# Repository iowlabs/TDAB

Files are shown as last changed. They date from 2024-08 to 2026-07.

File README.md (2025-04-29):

# Tremor Detection Adquisition Board

This device developed is an acquisition board for reading biometric signals from the human body, such as an EEG or EMG.

The board is based on the ADS1299, a 24-bit low-noise analog-to-digital converter developed for applications working with biopotential signals. The board uses a Teensy 4.1 as a DSP microcontroller to perform the tasks of synchronization, parameter configuration, ADC reading, and communication with the host.

The main feature of this equipment is that it has 6 analog signal conditioning channels that are fully configurable by software.

Each channel implements a band-pass filter whose gain and cut-off frequencies can be configured. The band-pass filter is implemented by two independent filters in cascade, one high-pass and one low-pass.

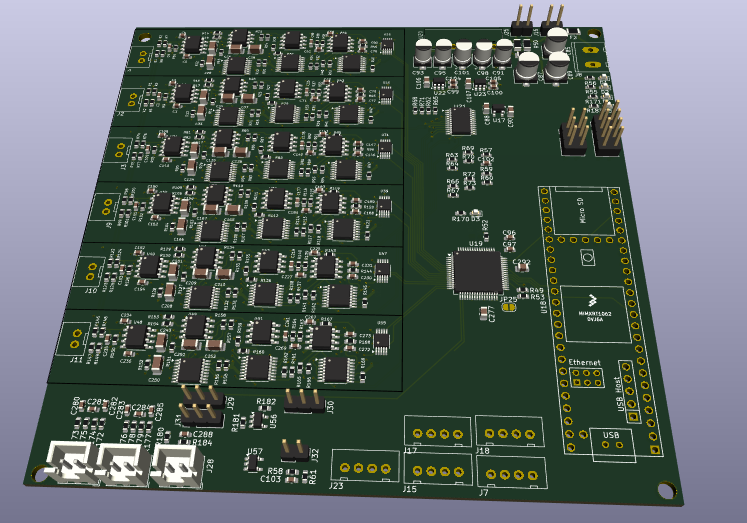
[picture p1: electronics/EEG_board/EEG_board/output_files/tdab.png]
pcb of TDAB


## Features
- 1ksps sampling rate
- 6 independent operating channels
- Bandpass configurable filter
	- Configurable lower cutoff frequency between 0.5Hz and 50Hz.
	- Gonfigurable upper cutoff frequency between 100Hz and 10kHz.
	- Configurable channel gain.
- Software-configurable channels
- 24-bit ADC and sampling rate up to 16kHz
- 16-bit accelerometer reading and up to 200g 9DoF
- Real-time reading and data display interface.

## LICENSES

| Item | License 	|
|---|---|
| Hardware | CERN-OHL-S-2.0 |
| Software | GPL-3.0-or-later|
| Firmware | GPL-3.0-or-later|
| Documentation | CC-BY-SA-4.0|

## Hardware description

## Electrónics

### Schematics

### Layout

### BOM

## 3D Model

## Firmware

## Software

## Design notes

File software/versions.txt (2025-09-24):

Firmware

	- main_v1_ino.
		- test dummy sin signals to valid channel
			-	1 24 bits signal for simulate ADC single channel
	    	-   6 16 bits signal for simulate Accelerometers signals
		- send data to 5k
		- use cdc native usb
		- send data with write function in raw mode.

software

	-plot_real_time_data.py
		- test to match with the main_v1_ino.
			- plot all 7 signal recived.
			-

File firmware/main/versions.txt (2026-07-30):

V1:
	- send simulated signals 6 chanels of 24 bits each for ADC and 6 channels of 16 bits for ACC.
	- Frame length:  2 + 4 + 6*3 + 6*2 + 2 = 38
	- Response to cmd:
		-	start.
 		- 	stop
 		- set
		- state?
V2:
	-read signal from ACC

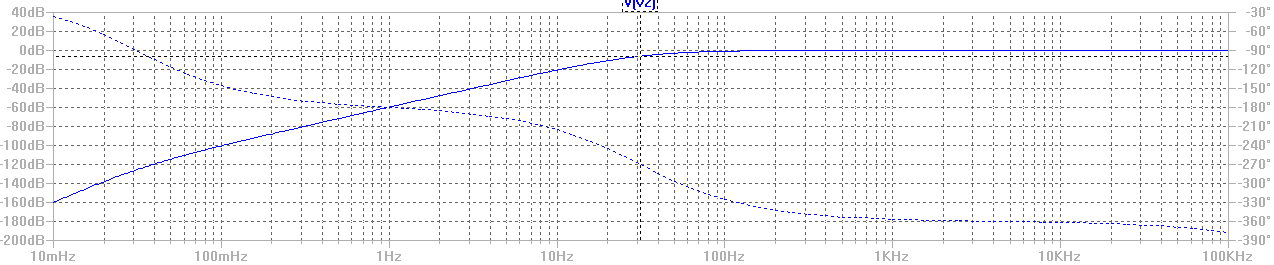
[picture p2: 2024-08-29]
electronics/simulations/img/fpa_segunda_etapa_frecuencia_superior_50hz.png

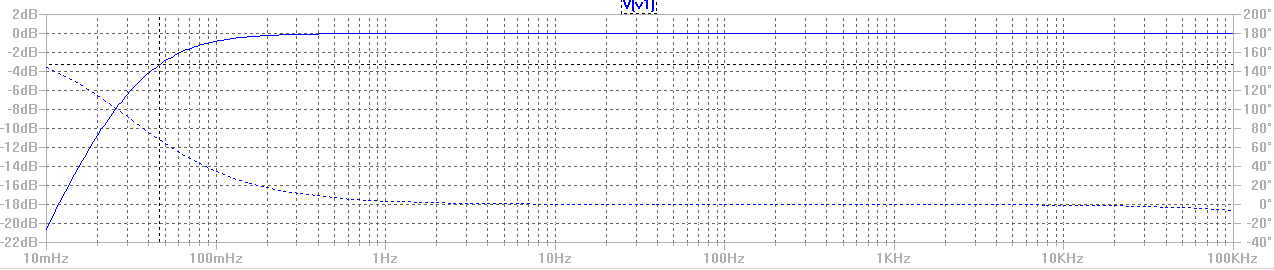
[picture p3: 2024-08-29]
electronics/simulations/img/fpa_priemra_etapa_50mHz.png

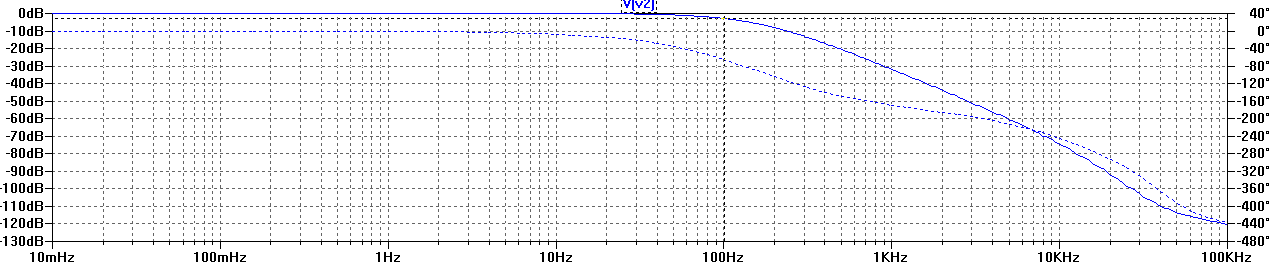
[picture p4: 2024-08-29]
electronics/simulations/img/fpb_segunda_etapa_inferior_100Hz.png

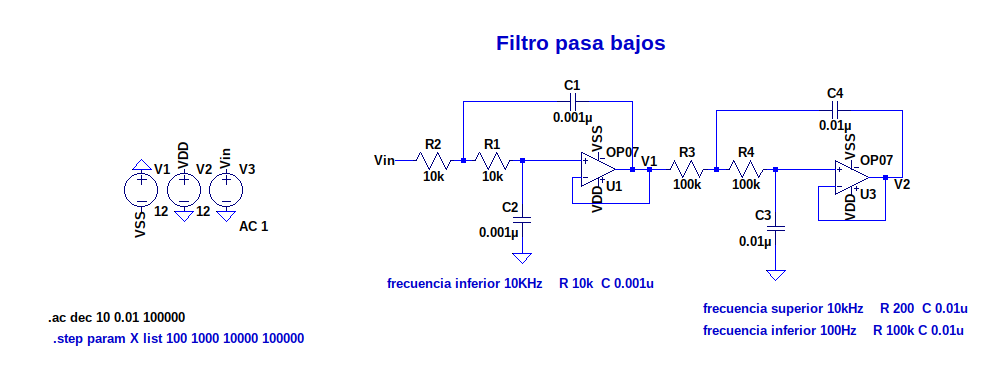
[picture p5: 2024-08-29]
electronics/simulations/img/sch_filtro_pasa_bajos.png

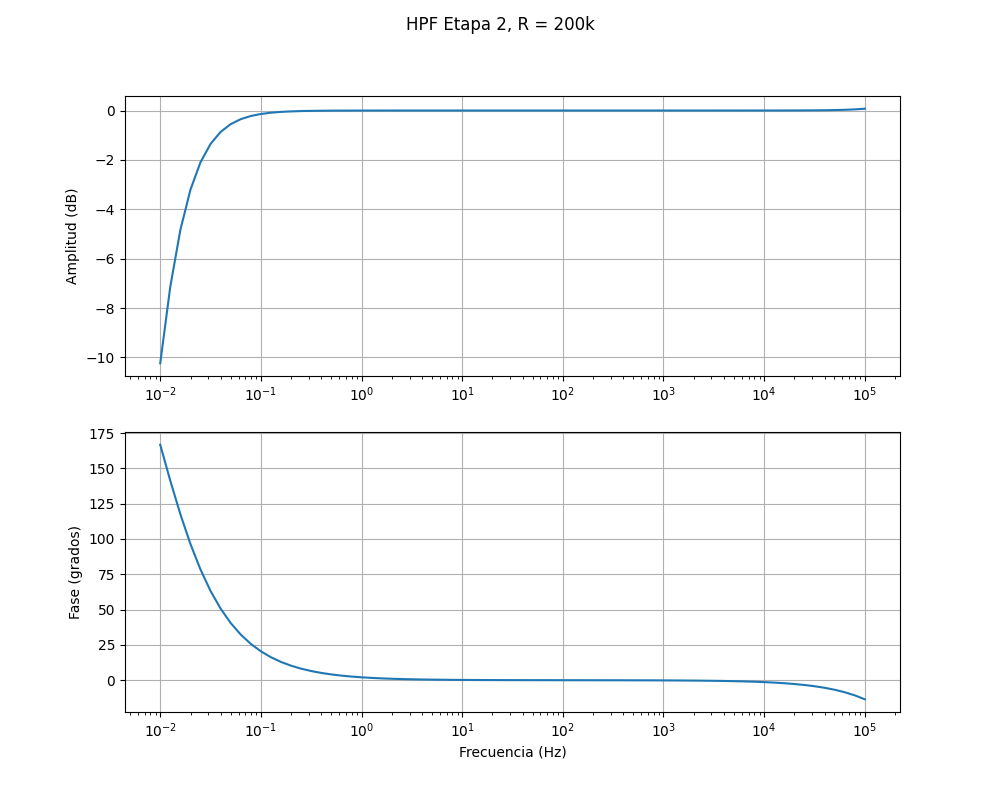
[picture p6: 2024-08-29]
electronics/simulations/img/hpf_e2_x200k.png

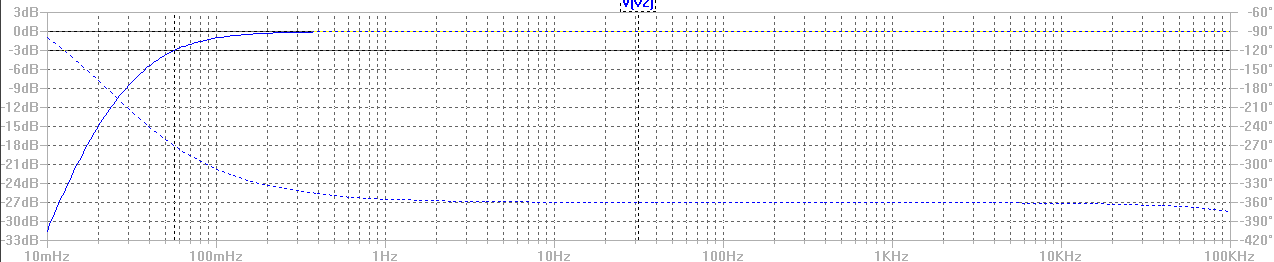
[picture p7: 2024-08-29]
electronics/simulations/img/fpa_segunda_etapa_frecuencia_inferior_50mHz.png

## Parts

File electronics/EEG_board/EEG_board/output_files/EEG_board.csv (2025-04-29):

Reference | Value | Datasheet | Footprint | Qty | DNP
C1,C3,C4,C6,C108,C110,C150,C152,C192,C194,C234,C236,C280,C282,C283,C285,C288 | 100p | ~ | Capacitor_SMD:C_0603_1608Metric | 17
C2,C5,C109,C151,C193,C235,C281,C284 | 1n | ~ | Capacitor_SMD:C_0603_1608Metric | 8
C7,C12,C13,C14,C21,C25,C26,C27,C29,C30,C32,C34,C44,C45,C47,C48,C49,C52,C53,C54,C61,C64,C65,C68,C73,C74,C75,C76,C81,C82,C83,C84,C96,C97,C102,C111,C114,C118,C120,C121,C122,C130,C131,C132,C134,C138,C140,C144,C145,C148,C149,C153,C156,C160,C162,C163,C164,C172,C173,C174,C176,C180,C182,C186,C187,C190,C191,C195,C198,C202,C204,C205,C206,C214,C215,C216,C218,C222,C224,C228,C229,C232,C233,C237,C240,C244,C246,C247,C248,C256,C257,C258,C260,C264,C266,C270,C271,C274,C275,C276,C279,C286,C287,C289,C290 | 100n | ~ | Capacitor_SMD:C_0603_1608Metric | 105
C8,C9,C10,C11,C15,C16,C17,C18,C22,C23,C24,C31,C39,C40,C41,C42,C43,C46,C50,C51,C57,C58,C59,C60,C63,C69,C70,C72,C86,C112,C113,C115,C116,C119,C123,C127,C128,C129,C133,C136,C137,C139,C142,C154,C155,C157,C158,C161,C165,C169,C170,C171,C175,C178,C179,C181,C184,C196,C197,C199,C200,C203,C207,C211,C212,C213,C217,C220,C221,C223,C226,C238,C239,C241,C242,C245,C249,C253,C254,C255,C259,C262,C263,C265,C268 | 10u | ~ | Capacitor_SMD:C_0805_2012Metric | 85
C19,C20,C28,C33,C35,C36,C37,C38,C117,C124,C125,C126,C159,C166,C167,C168,C201,C208,C209,C210,C243,C250,C251,C252 | 100u | ~ | Capacitor_SMD:C_1206_3216Metric | 24
C55,C56,C135,C177,C219,C261 | 200p | ~ | Capacitor_SMD:C_0603_1608Metric | 6
C62,C66,C67,C71,C141,C143,C183,C185,C225,C227,C267,C269 | 0.001u | ~ | Capacitor_SMD:C_0603_1608Metric | 12
C77,C78,C79,C80,C99,C100,C146,C147,C188,C189,C230,C231,C272,C273 | 0.1u | -- mixed values -- | Capacitor_SMD:C_0603_1608Metric | 14
C85,C89 | 5u | ~ | Capacitor_SMD:CP_Elec_5x5.4 | 2
C87 | 10u | ~ | Capacitor_SMD:CP_Elec_5x5.4 | 1
C88,C90,C92,C277,C278,C291,C292 | 1u | -- mixed values -- | Capacitor_SMD:C_0805_2012Metric | 7
C91 | 2.2u | ~ | Capacitor_SMD:CP_Elec_4x5.3 | 1
C93,C101 | 10u | ~ | Capacitor_SMD:CP_Elec_4x5.3 | 2
C94 | 100u | ~ | Capacitor_SMD:C_0805_2012Metric | 1
C95,C98 | 1u | ~ | Capacitor_SMD:CP_Elec_4x5.3 | 2
C103 | 1.5n | ~ | Capacitor_SMD:C_0603_1608Metric | 1
C104,C105 | 10n |  | Capacitor_SMD:C_0603_1608Metric | 2
C106,C107 | 2.2u |  | Capacitor_SMD:C_0805_2012Metric | 2
D1,D2,D3,D4,D5 | LED | ~ | LED_SMD:LED_0603_1608Metric | 5
F2 | FUSE |  | Fuse:Fuse_1206_3216Metric | 1
J1,J2,J3,J9,J10,J11 | HDR-2x1 |  | IoWLabsConnectors:JST-XH-2x1-2.5p-TH-V | 6
J4,J21 | Conn_02x03_Counter_Clockwise | ~ | Connector_PinHeader_2.54mm:PinHeader_2x03_P2.54mm_Vertical | 2
J7,J15,J17,J18,J23 | HDR-4x1 |  | IoWLabsConnectors:JST-XH-4x1-2.5P-TH-V | 5
J8 | HDR-2x1 |  | IoWLabsConnectors:Tb-2x1-5p-TH-V | 1
J16,J25 | ON OFF |  | Connector_PinHeader_2.54mm:PinHeader_1x02_P2.54mm_Vertical | 2
J20 | Conn_02x03_Counter_Clockwise | ~ |  | 1
J22 | Conn_02x04_Counter_Clockwise | ~ | Connector_PinHeader_2.54mm:PinHeader_2x04_P2.54mm_Vertical | 1
J24 | Conn_01x03 | ~ |  | 1
J26,J27,J28 | HDR-2x1 |  | Connector_JST:JST_XH_B2B-XH-A_1x02_P2.50mm_Vertical | 3
J29,J30,J31 | HDR-3x1 |  | Connector_PinHeader_2.54mm:PinHeader_1x03_P2.54mm_Vertical | 3
J32 | ~ |  | Connector_PinHeader_2.54mm:PinHeader_1x02_P2.54mm_Vertical | 1
JP1,JP2,JP3,JP4,JP5,JP6,JP7,JP8,JP9,JP10,JP11,JP12,JP13,JP14,JP15,JP16,JP17,JP18,JP19,JP20,JP21,JP22,JP23,JP24 | SolderJumper_2_Open | ~ | Jumper:SolderJumper-2_P1.3mm_Open_RoundedPad1.0x1.5mm | 24
R1,R2,R3,R4,R74,R75,R98,R99,R122,R123,R146,R147,R172,R173,R176,R177 | 10M | ~ | Resistor_SMD:R_0603_1608Metric | 16
R5,R6,R7,R8,R9,R10,R59,R60,R62,R63,R64,R65,R66,R67,R68,R69,R70,R71,R72,R73,R76,R77,R78,R100,R101,R102,R124,R125,R126,R148,R149,R150,R174,R175,R178,R179,R180,R184 | 4.7k | ~ | Resistor_SMD:R_0603_1608Metric | 38
R11,R12,R13,R16,R23,R24,R25,R26,R79,R80,R85,R86,R103,R104,R109,R110,R127,R128,R133,R134,R151,R152,R157,R158 | 160k | ~ | Resistor_SMD:R_0603_1608Metric | 24
R14,R15,R17,R19,R39,R40,R41,R42,R81,R82,R93,R94,R105,R106,R117,R118,R129,R130,R141,R142,R153,R154,R165,R166 | 20k | ~ | Resistor_SMD:R_0603_1608Metric | 24
R18,R20,R21,R22,R31,R32,R33,R34,R47,R48,R49,R52,R53,R83,R84,R89,R90,R97,R107,R108,R113,R114,R121,R131,R132,R137,R138,R145,R155,R156,R161,R162,R169 | 10k | ~ | Resistor_SMD:R_0603_1608Metric | 33
R27,R28,R29,R30,R87,R88,R111,R112,R135,R136,R159,R160,R181,R182 | 1k | ~ | Resistor_SMD:R_0603_1608Metric | 14
R35,R36,R37,R38,R91,R92,R115,R116,R139,R140,R163,R164 | 3.3k | ~ | Resistor_SMD:R_0603_1608Metric | 12
R43,R44,R45,R46,R57,R95,R96,R119,R120,R143,R144,R167,R168 | 33 | ~ | Resistor_SMD:R_0603_1608Metric | 13
R50,R54 | 636 | ~ | Resistor_SMD:R_1206_3216Metric | 2
R51 | 318 | ~ | Resistor_SMD:R_1206_3216Metric | 1
R55,R56,R170,R171,R183 | 470 |  | Resistor_SMD:R_0603_1608Metric | 5
R58,R61 | 1M | ~ | Resistor_SMD:R_0603_1608Metric | 2
U1,U2,U24,U32,U40,U48 | AD8421 | https://www.analog.com/media/en/technical-documentation/data-sheets/AD8421.pdf | Package_SO:SOIC-8_3.9x4.9mm_P1.27mm | 6
U3,U4,U11,U12,U25,U29,U33,U37,U41,U45,U49,U53 | OPA2277 | https://www.ti.com/lit/ds/symlink/opa2277.pdf | Package_SO:SOIC-8_3.9x4.9mm_P1.27mm | 12
U5,U6,U26,U34,U42,U50 | ~ |  | Package_SO:TSSOP-16_4.4x5mm_P0.65mm | 6
U7,U8,U27,U35,U43,U51 | OPA277 |  | Package_SO:SOIC-8_3.9x4.9mm_P1.27mm | 6
U9,U10,U13,U14,U28,U30,U36,U38,U44,U46,U52,U54 | AD5282 | https://www.analog.com/media/en/technical-documentation/data-sheets/AD5280_5282.pdf | Package_SO:TSSOP-16_4.4x5mm_P0.65mm | 12
U15,U16,U31,U39,U47,U55 | AD8475xRMZ | https://www.analog.com/media/en/technical-documentation/data-sheets/AD8475.pdf | Package_SO:MSOP-10_3x3mm_P0.5mm | 6
U17 | AP2112K-3.3 | https://www.diodes.com/assets/Datasheets/AP2112.pdf | Package_TO_SOT_SMD:SOT-23-5 | 1
U18 | Teensy4.1 |  | teensy:Teensy41 | 1
U19 | ADS1299-4PAG |  | Package_QFP:TQFP-64_10x10mm_P0.5mm | 1
U20 | MEA1D |  | IoWLabs:Miniature SIP 6p | 1
U21 | TCA9548APWR | http://www.ti.com/lit/ds/symlink/tca9548a.pdf | Package_SO:TSSOP-24_4.4x7.8mm_P0.65mm | 1
U22 | TPS730 | https://www.ti.com/lit/ds/symlink/tps730.pdf | Package_TO_SOT_SMD:SOT-23-5 | 1
U23 | TPS72325DBV | https://www.ti.com/lit/ds/symlink/tps723.pdf | Package_TO_SOT_SMD:SOT-23-5 | 1
U56,U57 | OPA376xxDBV | http://www.ti.com/lit/ds/symlink/opa376.pdf | Package_TO_SOT_SMD:SOT-23-5 | 2

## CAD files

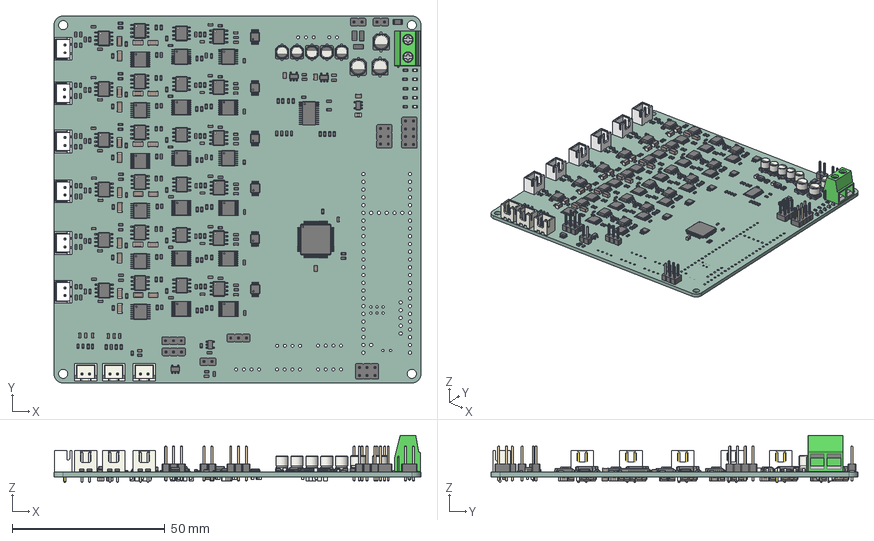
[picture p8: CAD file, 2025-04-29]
electronics/EEG_board/EEG_board/output_files/EEG_board.step
120.0 x 120.0 x 15.5 mm
R_0603_1608Metric x 181
TSSOP_16_44x5mm_P065mm x 18
SOIC_8_39x49mm_P127mm x 24
C_0603_1608Metric x 165
JST_B2B_XH_A x 3
PinHeader_2x03_P254mm_Vertical x 2
LED_0603_1608Metric x 5
C_1206_3216Metric x 24
R_1206_3216Metric x 3
BxB-XH-A x 5
CP_Elec_5x54 x 3
SOT_23_5 x 5
PinHeader_1x03_P254mm_Vertical x 3
C_0805_2012Metric x 95
CP_Elec_4x53 x 5
MSOP_10_3x3mm_P05mm x 6
PinHeader_1x02_P254mm_Vertical x 3
velleman_145849
PinHeader_2x04_P254mm_Vertical
TQFP_64_10x10mm_P05mm
BxB-XH-AM
Fuse_1206_3216Metric
TSSOP_24_44x78mm_P065mm
EEG_board_PCB

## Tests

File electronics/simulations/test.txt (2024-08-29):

Freq.	V(v2)
Step Information: X=10  (Run: 1/2)
1.00000000000000e-002	(-1.74019823255026e+002dB,-9.44142238655620e+001°)
1.25892541179417e-002	(-1.68266691565051e+002dB,-1.06643874493569e+002°)
1.58489319246111e-002	(-1.62943216732568e+002dB,-1.18376451347915e+002°)
1.99526231496888e-002	(-1.57989846033987e+002dB,-1.29077457922812e+002°)
2.51188643150958e-002	(-1.53329162326918e+002dB,-1.38446509856434e+002°)
3.16227766016838e-002	(-1.48884686090133e+002dB,-1.46399691245846e+002°)
3.98107170553497e-002	(-1.44591994036248e+002dB,-1.53003475312358e+002°)
5.01187233627273e-002	(-1.40402081004683e+002dB,-1.58404688907526e+002°)
6.30957344480194e-002	(-1.36280069907484e+002dB,-1.62778733617029e+002°)
7.94328234724282e-002	(-1.32202190459587e+002dB,-1.66298943384434e+002°)
1.00000000000000e-001	(-1.28152688936099e+002dB,-1.69121779468745e+002°)
1.25892541179417e-001	(-1.24121310229179e+002dB,-1.71381656450908e+002°)
1.58489319246111e-001	(-1.20101454711382e+002dB,-1.73190824878967e+002°)
1.99526231496888e-001	(-1.16088906228165e+002dB,-1.74641532827083e+002°)
2.51188643150958e-001	(-1.12080984072167e+002dB,-1.75808970051083e+002°)
3.16227766016838e-001	(-1.08075989383568e+002dB,-1.76754267521044e+002°)
3.98107170553498e-001	(-1.04072848501552e+002dB,-1.77527243568654e+002°)
5.01187233627273e-001	(-1.00070885237199e+002dB,-1.78168799765376e+002°)
6.30957344480194e-001	(-9.60696765248232e+001dB,-1.78712969572419e+002°)
7.94328234724282e-001	(-9.20689617440462e+001dB,-1.79188665554678e+002°)
1.00000000000000e+000	(-8.80685867199547e+001dB,-1.79621186152694e+002°)
1.25892541179417e+000	(-8.40684705451957e+001dB,1.79966453993194e+002°)
1.58489319246112e+000	(-8.00685881540947e+001dB,1.79552307685479e+002°)
1.99526231496888e+000	(-7.60689649219574e+001dB,1.79114332588308e+002°)
2.51188643150958e+000	(-7.20696821326675e+001dB,1.78629223578311e+002°)
3.16227766016838e+000	(-6.80708944859651e+001dB,1.78071180912394e+002°)
3.98107170553498e+000	(-6.40728633889329e+001dB,1.77410553195456e+002°)
5.01187233627273e+000	(-6.00760131263820e+001dB,1.76612291238502e+002°)
6.30957344480194e+000	(-5.60810218037536e+001dB,1.75634146705318e+002°)
7.94328234724283e+000	(-5.20889661140347e+001dB,1.74424551647807e+002°)
1.00000000000000e+001	(-4.81015497307030e+001dB,1.72920129272324e+002°)
1.25892541179417e+001	(-4.41214610232944e+001dB,1.71042827851081e+002°)
1.58489319246112e+001	(-4.01529283793183e+001dB,1.68696768157454e+002°)
1.99526231496888e+001	(-3.62025710348230e+001dB,1.65765104889905e+002°)
2.51188643150959e+001	(-3.22806756986659e+001dB,1.62107618904705e+002°)
3.16227766016839e+001	(-2.84030473694539e+001dB,1.57560524065243e+002°)
3.98107170553498e+001	(-2.45935401253556e+001dB,1.51941252852228e+002°)
5.01187233627273e+001	(-2.08871686525107e+001dB,1.45062784069776e+002°)
6.30957344480195e+001	(-1.73331634028411e+001dB,1.36763717849629e+002°)
7.94328234724284e+001	(-1.39963099524731e+001dB,1.26959412572396e+002°)
1.00000000000000e+002	(-1.09536484656423e+001dB,1.15711315800833e+002°)
1.25892541179417e+002	(-8.28341869661231e+000dB,1.03292197443103e+002°)
1.58489319246112e+002	(-6.04633175338751e+000dB,9.02025350322158e+001°)
1.99526231496889e+002	(-4.26609884951510e+000dB,7.70971054752489e+001°)
2.51188643150959e+002	(-2.92069995329697e+000dB,6.46337539774402e+001°)
3.16227766016839e+002	(-1.95051322162396e+000dB,5.33204097191535e+001°)
3.98107170553498e+002	(-1.27758924894302e+000dB,4.34379870295884e+001°)
5.01187233627274e+002	(-8.24583388851537e-001dB,3.50538682343925e+001°)
6.30957344480195e+002	(-5.26141078988396e-001dB,2.80861393497482e+001°)
7.94328234724284e+002	(-3.32444731390580e-001dB,2.23732515698479e+001°)
1.00000000000000e+003	(-2.07991326338076e-001dB,1.77258872308738e+001°)
1.25892541179417e+003	(-1.28564975422333e-001dB,1.39576259960651e+001°)
1.58489319246112e+003	(-7.81120599039810e-002dB,1.08995760339504e+001°)
1.99526231496889e+003	(-4.61860575348358e-002dB,8.40520143364722e+000°)
2.51188643150959e+003	(-2.60748681381090e-002dB,6.34997103718659e+000°)
3.16227766016839e+003	(-1.35094445089751e-002dB,4.62863793524825e+000°)
3.98107170553499e+003	(-5.80637692028558e-003dB,3.15165259953031e+000°)
5.01187233627274e+003	(-1.31456307409626e-003dB,1.84142365412322e+000°)
6.30957344480195e+003	(9.30710942899613e-004dB,6.28706923716737e-001°)
7.94328234724284e+003	(1.41161834844360e-003dB,-5.50820888498112e-001°)
1.00000000000000e+004	(2.29630222697998e-004dB,-1.75985974049809e+000°)
1.25892541179417e+004	(-2.87468988600570e-003dB,-3.06276758083835e+000°)
1.58489319246112e+004	(-8.58154736277754e-003dB,-4.52897014750709e+000°)
1.99526231496889e+004	(-1.81477486154124e-002dB,-6.23666673112673e+000°)
2.51188643150959e+004	(-3.36998645667388e-002dB,-8.27701639156080e+000°)
3.16227766016839e+004	(-5.87460514075103e-002dB,-1.07589854548845e+001°)
3.98107170553499e+004	(-9.90577657210530e-002dB,-1.38149499622919e+001°)
5.01187233627274e+004	(-1.64196853025036e-001dB,-1.76067748479447e+001°)
6.30957344480196e+004	(-2.70167481516560e-001dB,-2.23308596390882e+001°)
7.94328234724285e+004	(-4.43914961514144e-001dB,-2.82171162486471e+001°)
1.00000000000000e+005	(-7.30291612203267e-001dB,-3.55083598772035e+001°)
Step Information: X=1K  (Run: 2/2)
1.00000000000000e-002	(-9.40479035700138e+001dB,-9.10238104030550e+001°)
1.25892541179417e-002	(-8.82867572262030e+001dB,-1.04279870982478e+002°)
1.58489319246111e-002	(-8.29584087677399e+001dB,-1.16914514443911e+002°)
1.99526231496888e-002	(-7.80022629730441e+001dB,-1.28440499512006e+002°)
2.51188643150958e-002	(-7.33403074398961e+001dB,-1.38600968769340e+002°)
3.16227766016838e-002	(-6.88957895220219e+001dB,-1.47353923376268e+002°)
3.98107170553497e-002	(-6.46042772552235e+001dB,-1.54808263059890e+002°)
5.01187233627273e-002	(-6.04170196674282e+001dB,-1.61155928678534e+002°)
6.30957344480194e-002	(-5.62997111651473e+001dB,-1.66622436142911e+002°)
7.94328234724282e-002	(-5.22295920939823e+001dB,-1.71438760681312e+002°)
1.00000000000000e-001	(-4.81925726346801e+001dB,-1.75829337276593e+002°)
1.25892541179417e-001	(-4.41810639333009e+001dB,1.79990007603049e+002°)
1.58489319246111e-001	(-4.01926853403190e+001dB,1.75808847462128e+002°)
1.99526231496888e-001	(-3.62298407708012e+001dB,1.71416741845682e+002°)
2.51188643150958e-001	(-3.23001464434101e+001dB,1.66597827343420e+002°)
3.16227766016838e-001	(-2.84177278778070e+001dB,1.61127625945424e+002°)
3.98107170553498e-001	(-2.46053928081235e+001dB,1.54775148280309e+002°)
5.01187233627273e-001	(-2.08975096399199e+001dB,1.47314954777667e+002°)
6.30957344480194e-001	(-1.73429039648955e+001dB,1.38555363939133e+002°)
7.94328234724282e-001	(-1.40060800667793e+001dB,1.28388024547962e+002°)
1.00000000000000e+000	(-1.09638302907612e+001dB,1.16855827584884e+002°)
1.25892541179417e+000	(-8.29413299081123e+000dB,1.04216754221330e+002°)
1.58489319246112e+000	(-6.05744948333396e+000dB,9.09590488591414e+001°)
1.99526231496888e+000	(-4.27733654599023e+000dB,7.77271744944123e+001°)
2.51188643150958e+000	(-2.93177132385215e+000dB,6.51706713999267e+001°)
3.16227766016838e+000	(-1.96124159246418e+000dB,5.37914748332939e+001°)
3.98107170553498e+000	(-1.28792710058326e+000dB,4.38667294428013e+001°)
5.01187233627273e+000	(-8.34568785244029e-001dB,3.54618093374874e+001°)
6.30957344480194e+000	(-5.35844956418612e-001dB,2.84940924939659e+001°)
7.94328234724283e+000	(-3.41936384226482e-001dB,2.28023793058472e+001°)
1.00000000000000e+001	(-2.17323001308925e-001dB,1.81987202074977e+001°)
1.25892541179417e+001	(-1.37767411902710e-001dB,1.44991687344159e+001°)
1.58489319246112e+001	(-8.71937300911168e-002dB,1.15385749420563e+001°)
1.99526231496888e+001	(-5.51317255146435e-002dB,9.17563771319075e+000°)
2.51188643150959e+001	(-3.48409075008455e-002dB,7.29284925700857e+000°)
3.16227766016839e+001	(-2.20138350044642e-002dB,5.79415865061640e+000°)
3.98107170553498e+001	(-1.39107401984835e-002dB,4.60188045855411e+000°)
5.01187233627273e+001	(-8.79413703658267e-003dB,3.65359086255900e+000°)
6.30957344480195e+001	(-5.56422096594850e-003dB,2.89932724865881e+000°)
7.94328234724284e+001	(-3.52565353395170e-003dB,2.29919201913746e+000°)
1.00000000000000e+002	(-2.23914230469583e-003dB,1.82136108287394e+000°)
1.25892541179417e+002	(-1.42728529093380e-003dB,1.44045605194493e+000°)
1.58489319246112e+002	(-9.14959069789573e-004dB,1.13622636426173e+000°)
1.99526231496889e+002	(-5.91624081350750e-004dB,8.92487734032868e-001°)
2.51188643150959e+002	(-3.87506741662784e-004dB,6.96268739129578e-001°)
3.16227766016839e+002	(-2.58555557879625e-004dB,5.37124287330503e-001°)
3.98107170553498e+002	(-1.76939271804051e-004dB,4.06581503538501e-001°)
5.01187233627274e+002	(-1.25042128436278e-004dB,2.97689584079582e-001°)
6.30957344480195e+002	(-9.16625650467012e-005dB,2.04650174966246e-001°)
7.94328234724284e+002	(-6.95957695964434e-005dB,1.22508855371992e-001°)
1.00000000000000e+003	(-5.40786862750463e-005dB,4.68914291903392e-002°)
1.25892541179417e+003	(-4.17619745542902e-005dB,-2.62289529717462e-002°)
1.58489319246112e+003	(-2.99870796444975e-005dB,-1.00746211255744e-001°)
1.99526231496889e+003	(-1.62123949482522e-005dB,-1.80628698601221e-001°)
2.51188643150959e+003	(2.53533541605152e-006dB,-2.70130548482425e-001°)
3.16227766016839e+003	(3.03027797606739e-005dB,-3.74018272540262e-001°)
3.98107170553499e+003	(7.30834585190821e-005dB,-4.97824699841008e-001°)
5.01187233627274e+003	(1.40111360310954e-004dB,-6.48143833149596e-001°)
6.30957344480195e+003	(2.45853881384609e-004dB,-8.32982430118509e-001°)
7.94328234724284e+003	(4.13134063534647e-004dB,-1.06218724413937e+000°)
1.00000000000000e+004	(6.78055559696659e-004dB,-1.34797109997461e+000°)
1.25892541179417e+004	(1.09779210851594e-003dB,-1.70556666395986e+000°)
1.58489319246112e+004	(1.76291967426965e-003dB,-2.15404440978828e+000°)
1.99526231496889e+004	(2.81694508750896e-003dB,-2.71734170414990e+000°)
2.51188643150959e+004	(4.48722615752184e-003dB,-3.42556453384747e+000°)
3.16227766016839e+004	(7.13390622793595e-003dB,-4.31664462058244e+000°)
3.98107170553499e+004	(1.13272965683359e-002dB,-5.43846701364949e+000°)
5.01187233627274e+004	(1.79700825281762e-002dB,-6.85163520275699e+000°)
6.30957344480196e+004	(2.84898993721404e-002dB,-8.63312880295498e+000°)
7.94328234724285e+004	(4.51417118334189e-002dB,-1.08812654977546e+001°)
1.00000000000000e+005	(7.14797349534276e-002dB,-1.37226699744507e+001°)

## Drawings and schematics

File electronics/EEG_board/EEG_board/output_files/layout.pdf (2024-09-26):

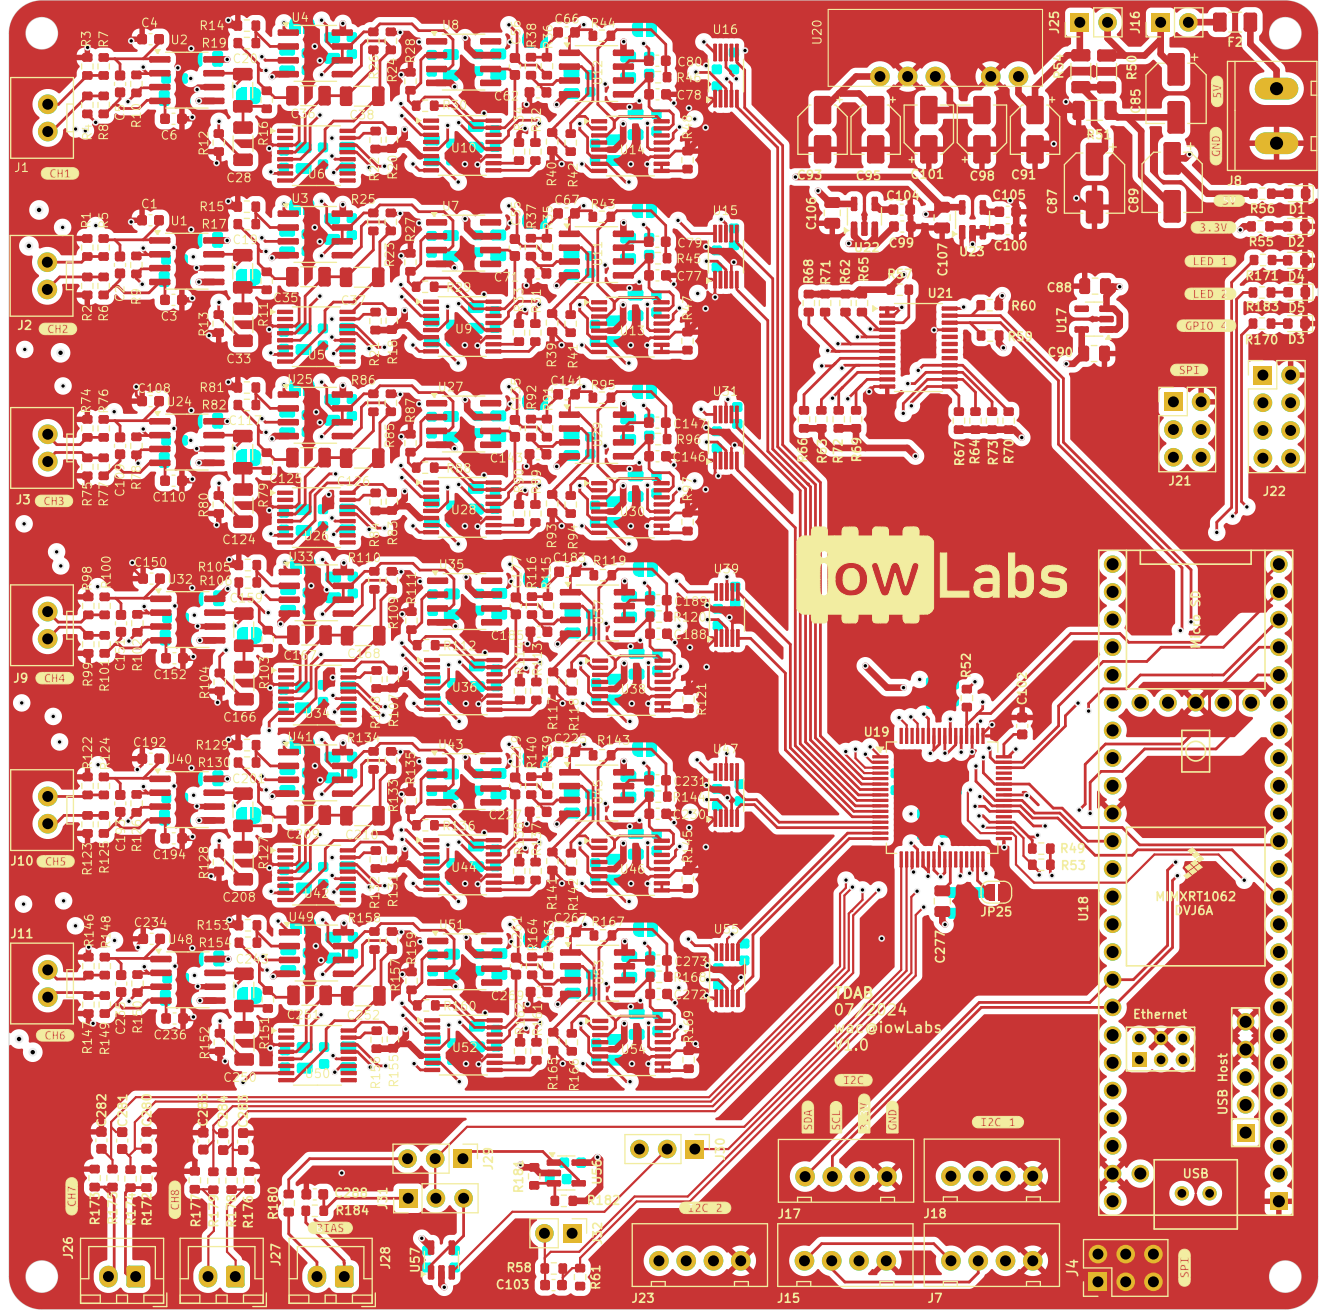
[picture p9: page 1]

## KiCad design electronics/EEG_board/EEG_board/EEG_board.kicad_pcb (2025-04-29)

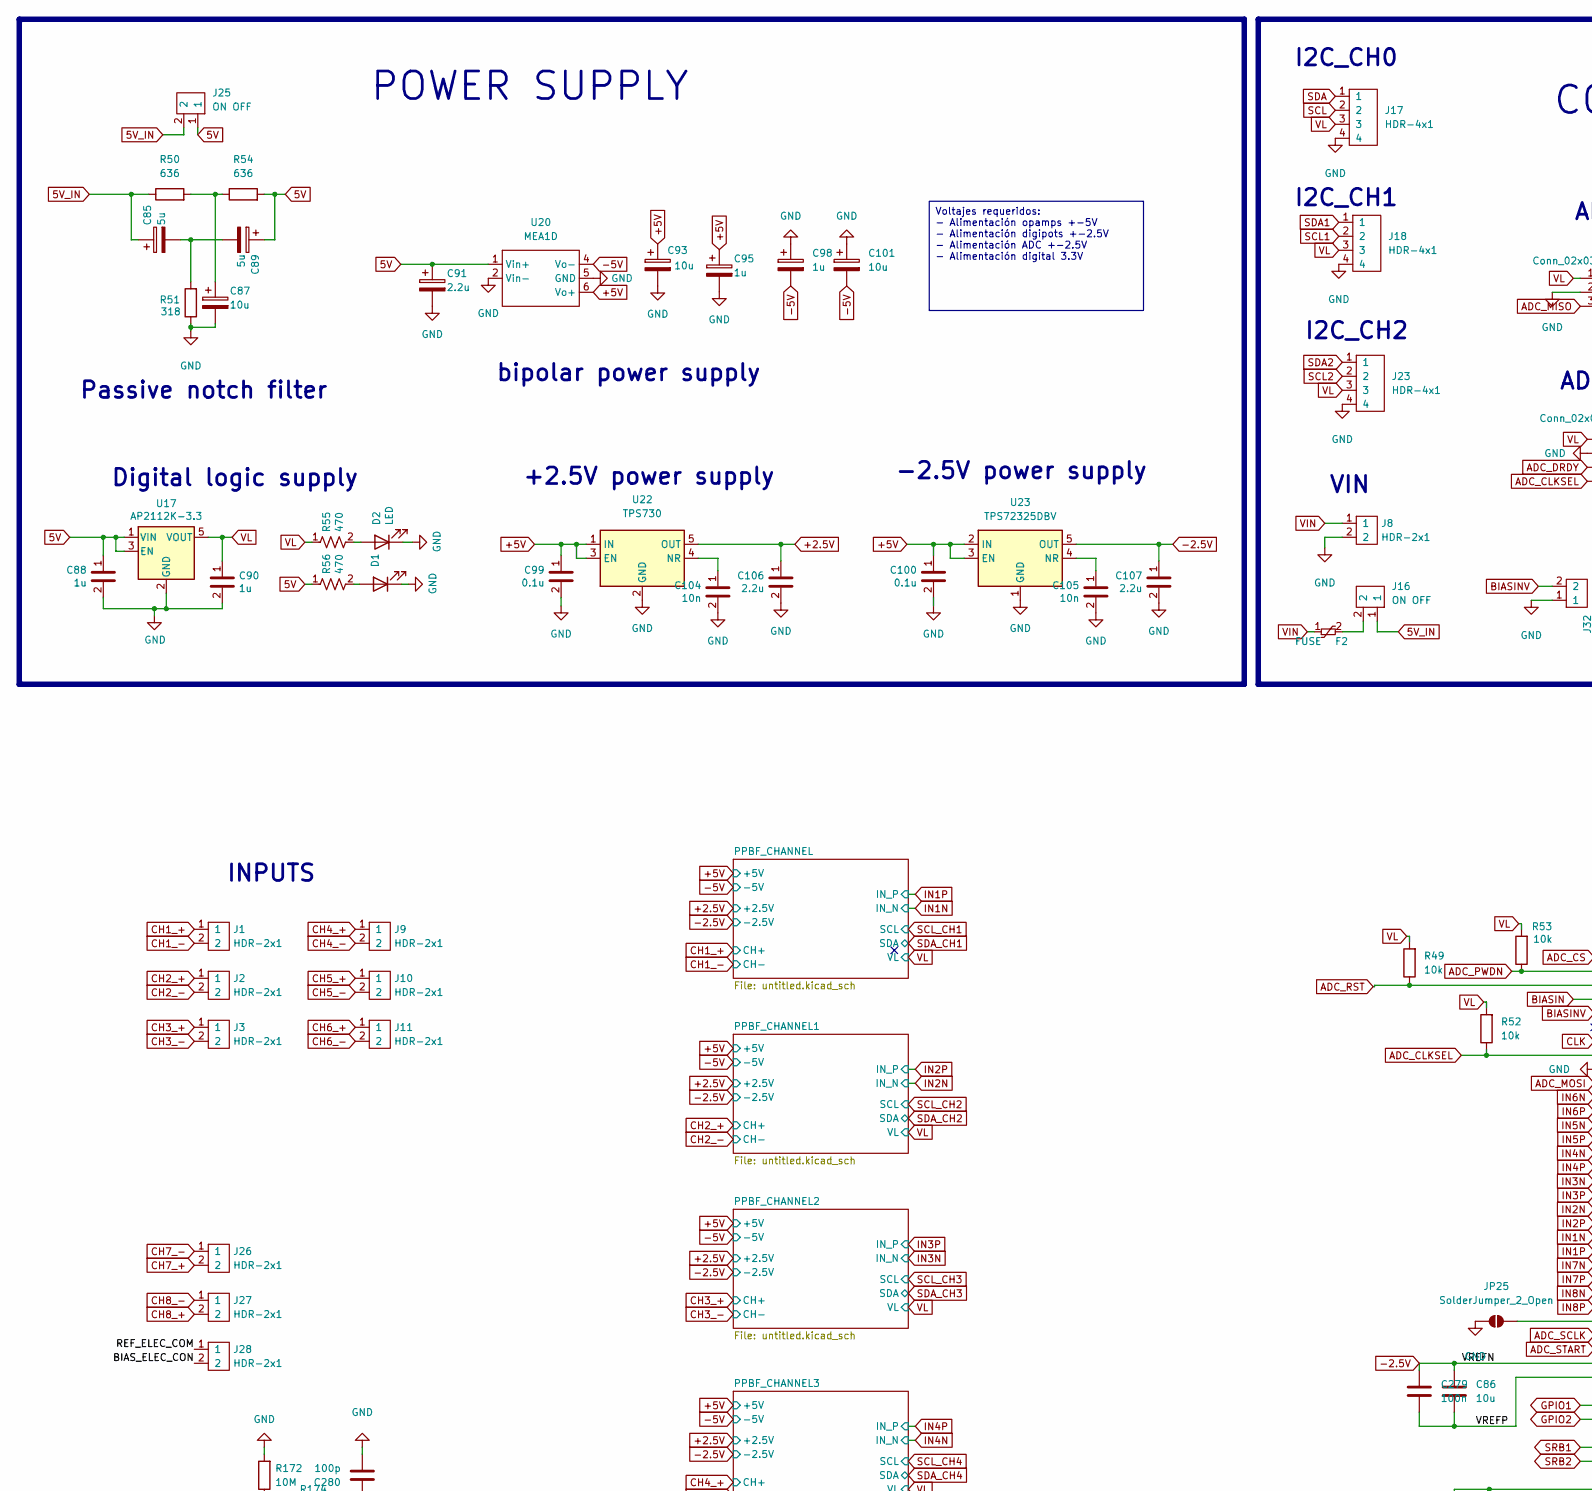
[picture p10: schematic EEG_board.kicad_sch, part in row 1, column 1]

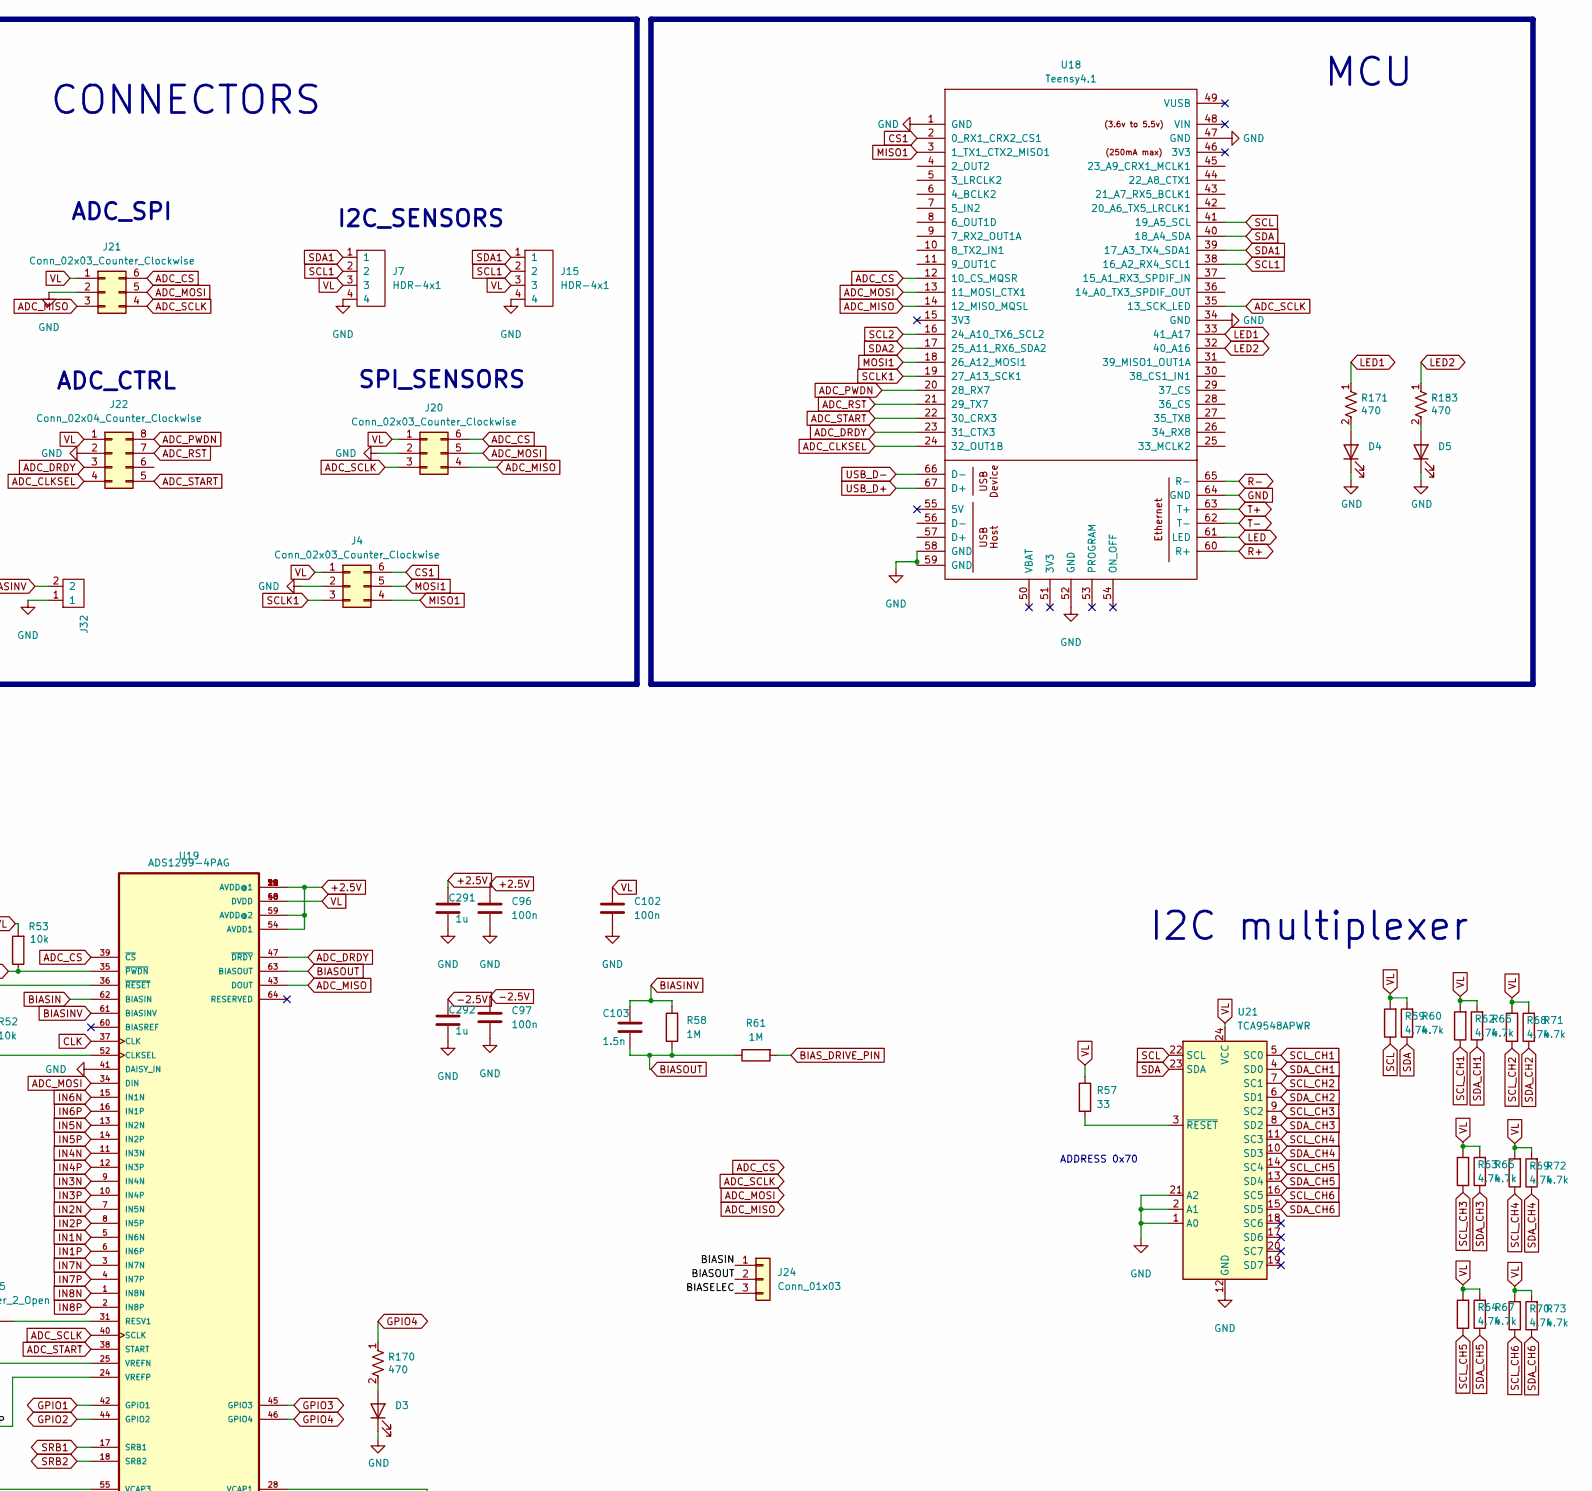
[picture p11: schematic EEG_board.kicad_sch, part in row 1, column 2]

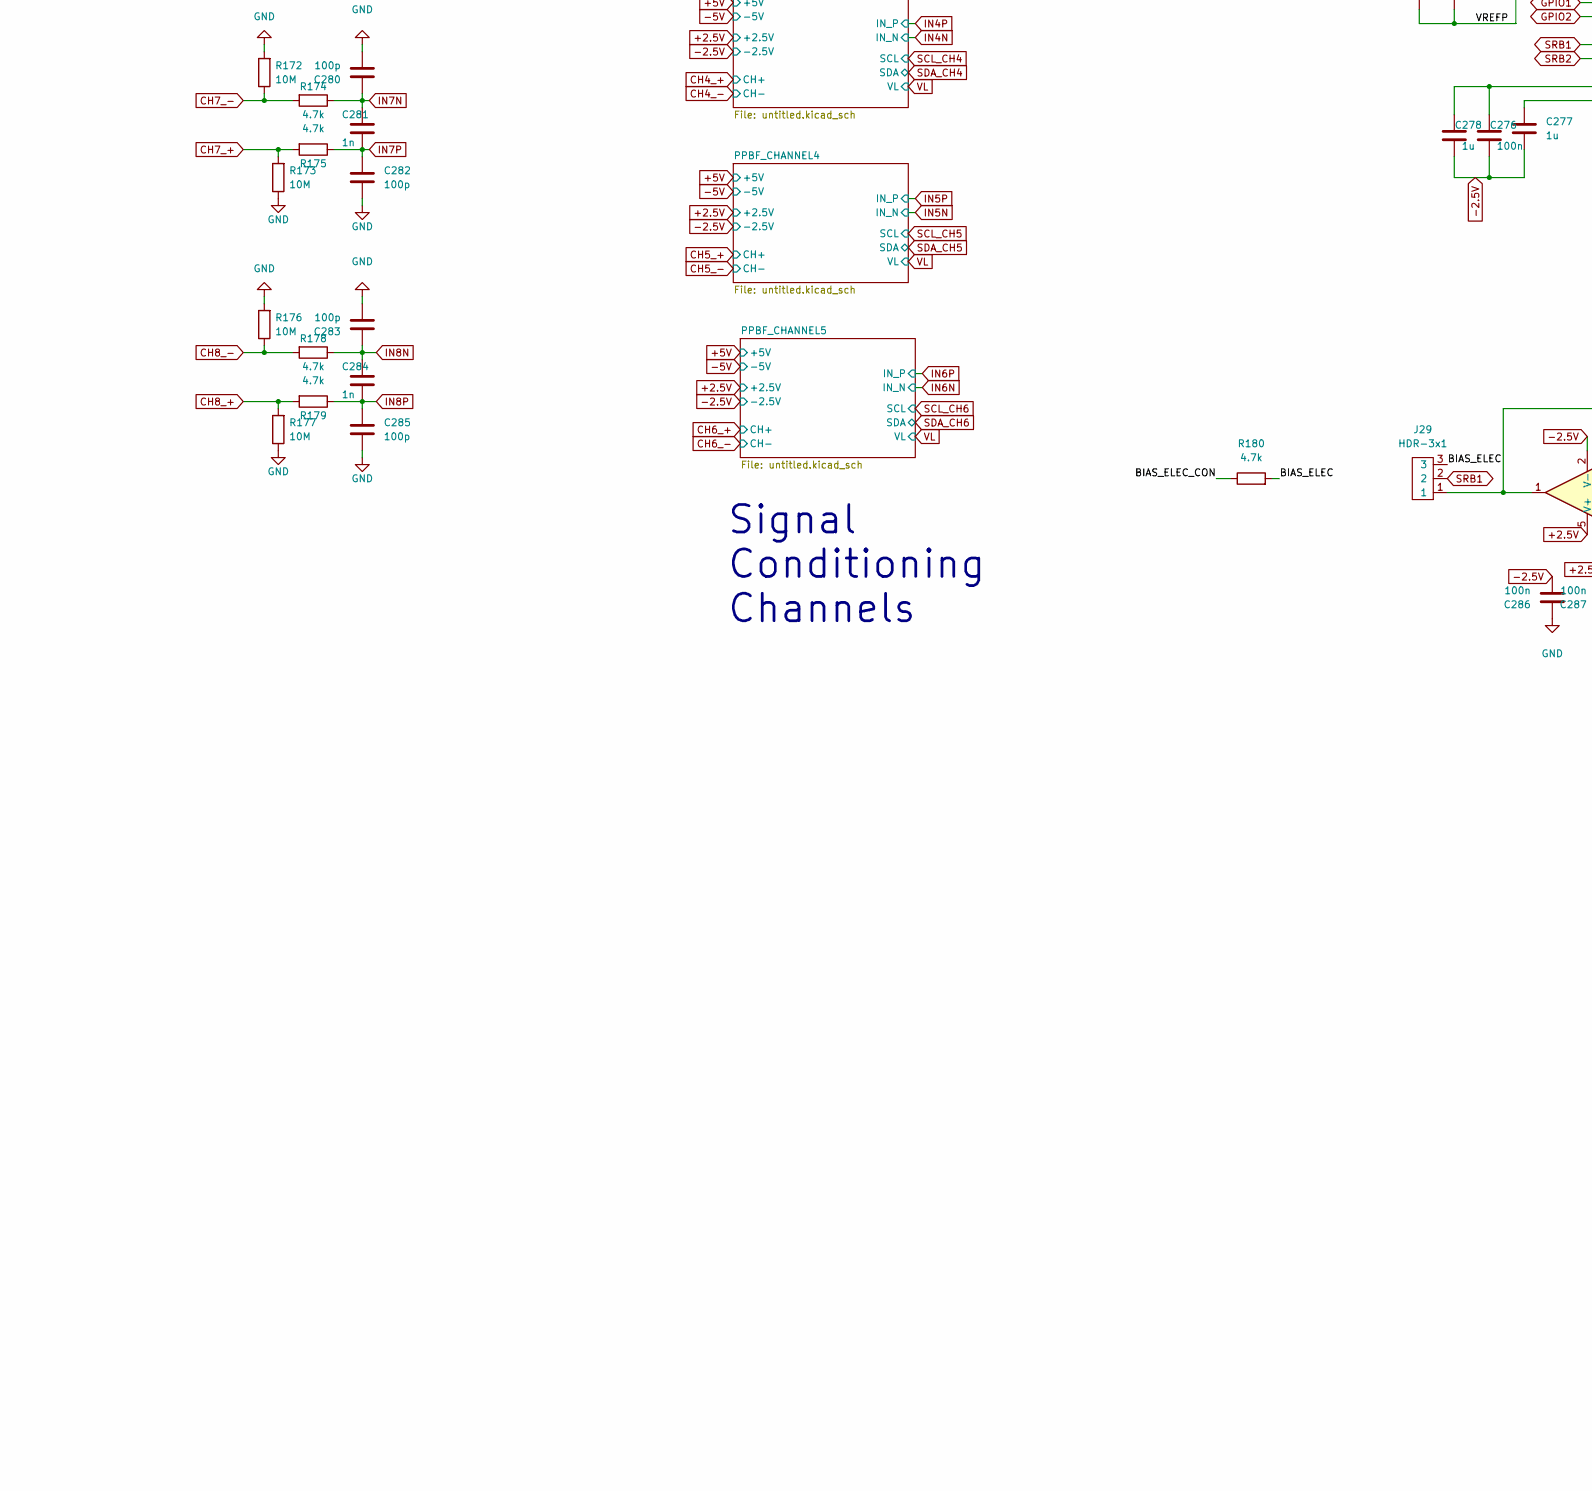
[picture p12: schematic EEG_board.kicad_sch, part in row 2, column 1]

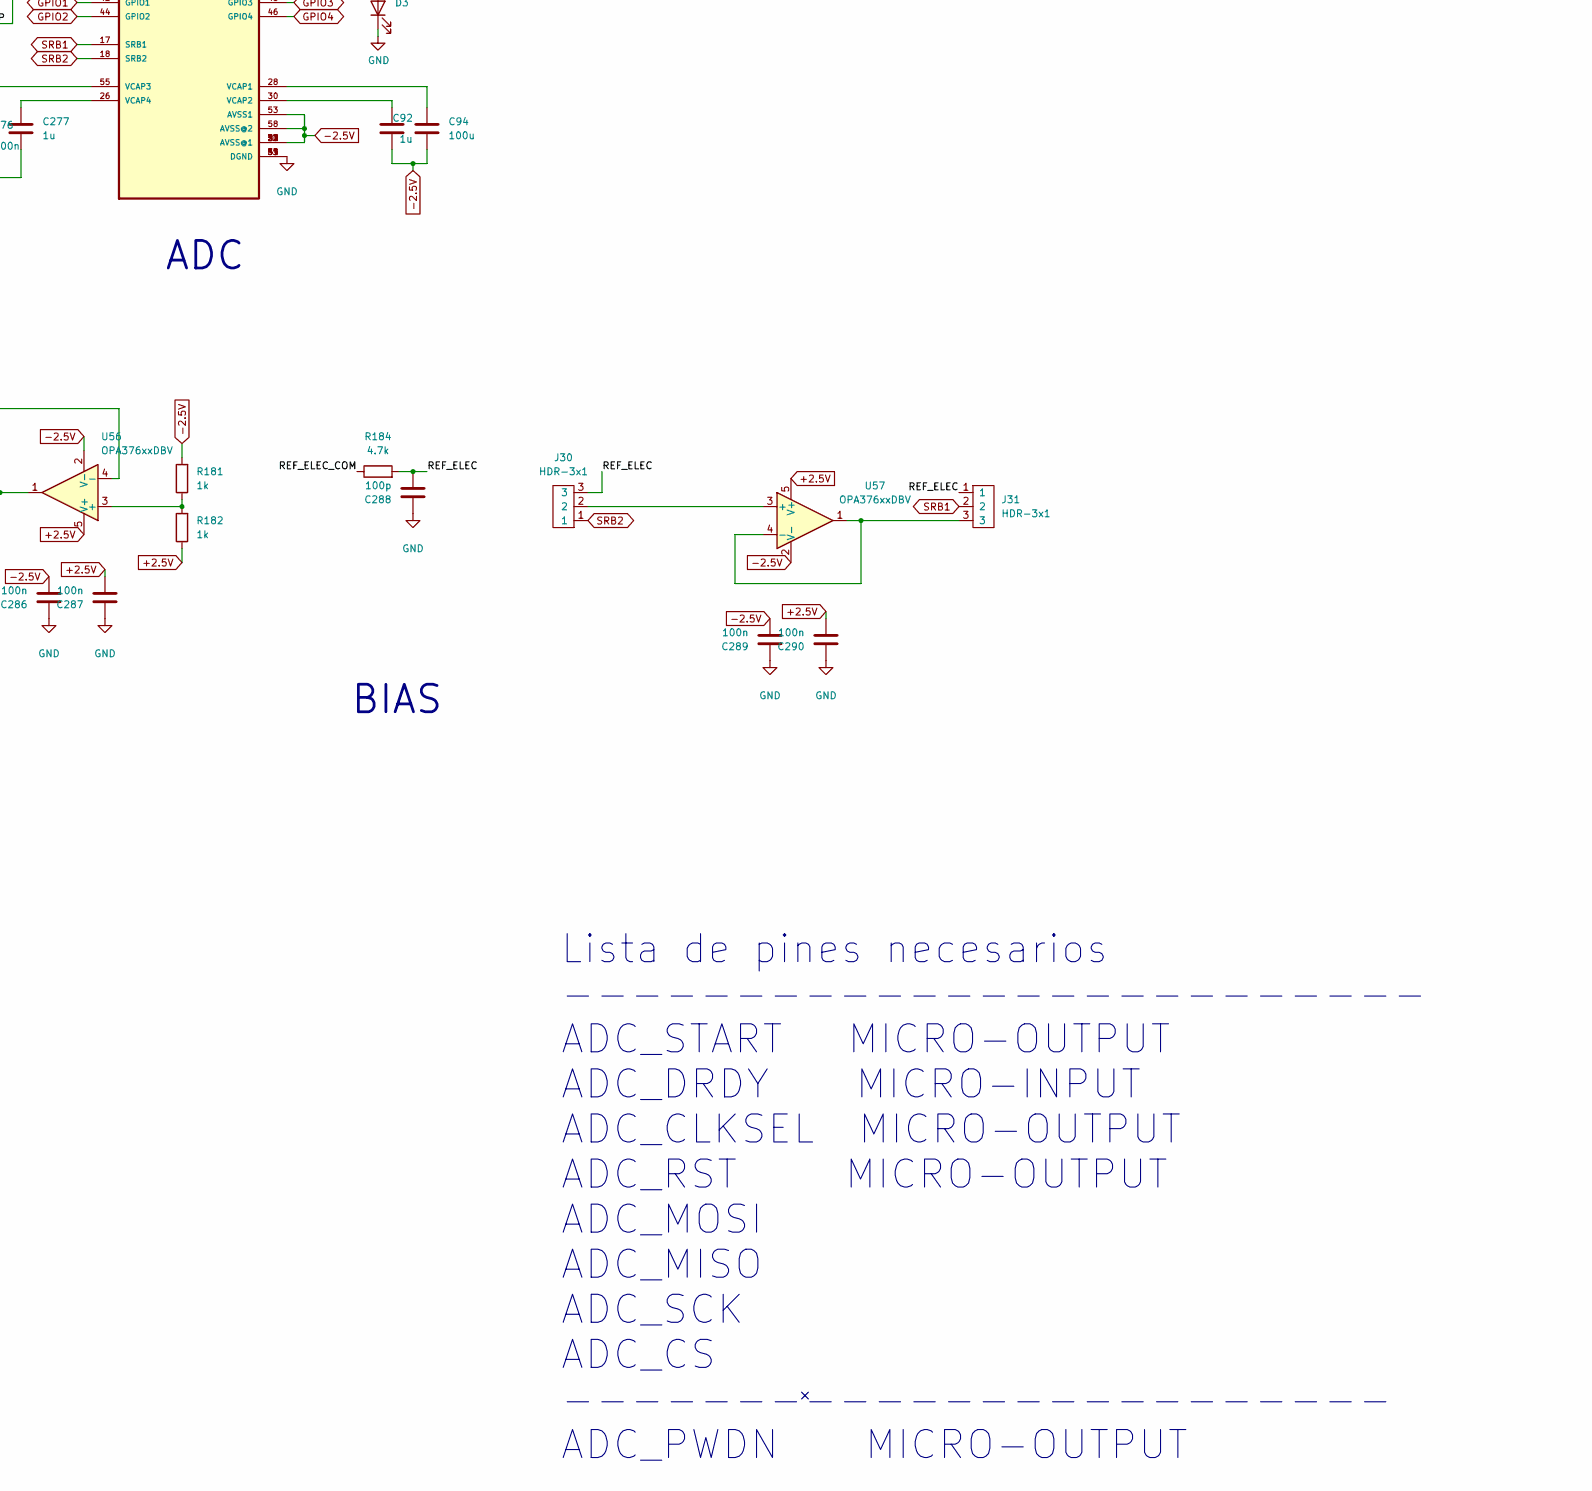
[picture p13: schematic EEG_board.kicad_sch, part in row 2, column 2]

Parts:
C85, C89: 5u; CP_Elec_5x5.4
C86: 10u; C_0805_2012Metric
C87: 10u; CP_Elec_5x5.4
C88, C90: 1u; C_0805_2012Metric; Voltage rated 16V
C91: 2.2u; CP_Elec_4x5.3
C92, C277, C278, C291, C292: 1u; C_0805_2012Metric
C93, C101: 10u; CP_Elec_4x5.3
C94: 100u; C_0805_2012Metric
C95, C98: 1u; CP_Elec_4x5.3
C96, C97, C102, C276, C279, C286, C287, C289, C290: 100n; C_0603_1608Metric
C99, C100: 0.1u; C_0603_1608Metric; Voltage rated 16V
C103: 1.5n; C_0603_1608Metric
C104, C105: 10n; C_0603_1608Metric; Voltage rated 16V
C106, C107: 2.2u; C_0805_2012Metric; Voltage rated 16V
C280, C282, C283, C285, C288: 100p; C_0603_1608Metric
C281, C284: 1n; C_0603_1608Metric
D1, D2, D3, D4, D5: LED; LED_0603_1608Metric
F2: FUSE; Fuse_1206_3216Metric
J1, J2, J3, J9, J10, J11: HDR-2x1; JST-XH-2x1-2.5p-TH-V
J4, J21: Conn_02x03_Counter_Clockwise; PinHeader_2x03_P2.54mm_Vertical
J7, J15, J17, J18, J23: HDR-4x1; JST-XH-4x1-2.5P-TH-V
J8: HDR-2x1; Tb-2x1-5p-TH-V
J16, J25: ON OFF; PinHeader_1x02_P2.54mm_Vertical
J20: Conn_02x03_Counter_Clockwise
J22: Conn_02x04_Counter_Clockwise; PinHeader_2x04_P2.54mm_Vertical
J24: Conn_01x03
J26, J27, J28: HDR-2x1; JST_XH_B2B-XH-A_1x02_P2.50mm_Vertical
J29, J30, J31: HDR-3x1; PinHeader_1x03_P2.54mm_Vertical
J32: PinHeader_1x02_P2.54mm_Vertical
JP25: SolderJumper_2_Open; SolderJumper-2_P1.3mm_Open_RoundedPad1.0x1.5mm
R49, R52, R53: 10k; R_0603_1608Metric
R50, R54: 636; R_1206_3216Metric
R51: 318; R_1206_3216Metric
R55, R56, R170, R171, R183: 470; R_0603_1608Metric
R57: 33; R_0603_1608Metric
R58, R61: 1M; R_0603_1608Metric
R59, R60, R62, R63, R64, R65, R66, R67, R68, R69, R70, R71, R72, R73, R174, R175, R178, R179, R180, R184: 4.7k; R_0603_1608Metric
R172, R173, R176, R177: 10M; R_0603_1608Metric
R181, R182: 1k; R_0603_1608Metric
U17: AP2112K-3.3; SOT-23-5
U18: Teensy4.1; Teensy41
U19: ADS1299-4PAG; TQFP-64_10x10mm_P0.5mm
U20: MEA1D; Miniature SIP 6p
U21: TCA9548APWR; TSSOP-24_4.4x7.8mm_P0.65mm
U22: TPS730; SOT-23-5
U23: TPS72325DBV; SOT-23-5
U56, U57: OPA376xxDBV; SOT-23-5

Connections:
5V: C88.1, C89.1, C91.1, J25.1, R54.2, R56.1, U17.1 (VIN), U17.3 (EN), U20.1 (Vin+)
5V_IN: C85.1, J16.1, J25.2, R50.1
+2.5V: C96.1, C106.1, C287.2, C290.2, C291.1, R182.1, U19.19 (AVDD@1), U19.21 (AVDD@1), U19.22 (AVDD@1), U19.54 (AVDD1), U19.56 (AVDD@1), U19.59 (AVDD@2), U22.5 (OUT), U56.5 (V+), U57.5 (V+); also elsewhere on the board
+5V: C93.1, C95.1, C99.1, C100.1, U20.6 (Vo+), U22.1 (IN), U22.3 (EN), U23.2 (IN), U23.3 (EN); also elsewhere on the board
-2.5V: C86.1, C92.2, C94.2, C97.1, C107.1, C276.2, C277.2, C278.2, C279.1, C286.2, C289.2, C292.1, R181.2, U19.20 (AVSS@1), U19.23 (AVSS@1), U19.25 (VREFN), U19.32 (AVSS@1), U19.53 (AVSS1), U19.57 (AVSS@1), U19.58 (AVSS@2), U23.5 (OUT), U56.2 (V-), U57.2 (V-); also elsewhere on the board
-5V: C98.2, C101.2, U20.4 (Vo-); also elsewhere on the board
/BIAS_ELEC: J29.3, R180.2
/BIAS_ELEC_CON: J28.2, R180.1
/REF_ELEC: C288.2, J30.3, J31.1, R184.2
/REF_ELEC_COM: J28.1, R184.1
/VREFP: C86.2, C279.2, U19.24 (VREFP)
ADC_CLKSEL: J22.4, R52.1, U18.24 (32_OUT1B), U19.52 (CLKSEL)
ADC_CS: J20.6, J21.6, U18.12 (10_CS_MQSR), U19.39 (~CS)
ADC_DRDY: J22.3, U18.23 (31_CTX3), U19.47 (~DRDY)
ADC_MISO: J20.4, J21.3, U18.14 (12_MISO_MQSL), U19.43 (DOUT)
ADC_MOSI: J20.5, J21.5, U18.13 (11_MOSI_CTX1), U19.34 (DIN)
ADC_PWDN: J22.8, R53.1, U18.20 (28_RX7), U19.35 (~PWDN)
ADC_RST: J22.7, R49.1, U18.21 (29_TX7), U19.36 (~RESET)
ADC_SCLK: J20.3, J21.4, U18.35 (13_SCK_LED), U19.40 (SCLK)
ADC_START: J22.5, U18.22 (30_CRX3), U19.38 (START)
BIASIN: U19.62 (BIASIN)
BIASINV: C103.1, J32.2, R58.2, U19.61 (BIASINV)
BIASOUT: C103.2, R58.1, R61.1, U19.63 (BIASOUT)
BIAS_DRIVE_PIN: R61.2
CH1_+: J1.1; also elsewhere on the board
CH1_-: J1.2; also elsewhere on the board
CH2_+: J2.1; also elsewhere on the board
CH2_-: J2.2; also elsewhere on the board
CH3_+: J3.1; also elsewhere on the board
CH3_-: J3.2; also elsewhere on the board
CH4_+: J9.1; also elsewhere on the board
CH4_-: J9.2; also elsewhere on the board
CH5_+: J10.1; also elsewhere on the board
CH5_-: J10.2; also elsewhere on the board
CH6_+: J11.1; also elsewhere on the board
CH6_-: J11.2; also elsewhere on the board
CH7_+: J26.2, R173.2, R175.2
CH7_-: J26.1, R172.1, R174.2
CH8_+: J27.2, R177.2, R179.2
CH8_-: J27.1, R176.1, R178.2
CLK: U19.37 (CLK)
CS1: J4.6, U18.2 (0_RX1_CRX2_CS1)
GND: C87.2, C88.2, C90.2, C91.2, C93.2, C95.2, C96.2, C97.2, C98.1, C99.2, C100.2, C101.1, C102.2, C104.2, C105.2, C106.2, C107.2, C280.2, C282.2, C283.2, C285.2, C286.1, C287.1, C288.1, C289.1, C290.1, C291.2, C292.2, D1.1 (K), D2.1 (K), D3.1 (K), D4.1 (K), D5.1 (K), J4.2, J7.4, J8.2, J15.4, J17.4, J18.4, J20.2, J21.2, J22.2, J23.4, J32.1, JP25.1 (A), R51.1, R172.2, R173.1, R176.2, R177.1, U17.2 (GND), U18.1 (GND), U18.34 (GND), U18.47 (GND), U18.52 (GND), U18.58 (GND), U18.59 (GND), U18.64 (GND), U19.33 (DGND), U19.41 (DAISY_IN), U19.49 (DGND), U19.51 (DGND), U20.2 (Vin-), U20.5 (GND), U21.1 (A0), U21.2 (A1), U21.12 (GND), U21.21 (A2), U22.2 (GND), U23.1 (GND); also elsewhere on the board
GPIO1: U19.42 (GPIO1)
GPIO2: U19.44 (GPIO2)
GPIO3: U19.45 (GPIO3)
GPIO4: R170.1, U19.46 (GPIO4)
IN1N: U19.5 (IN6N); also elsewhere on the board
IN1P: U19.6 (IN6P); also elsewhere on the board
IN2N: U19.7 (IN5N); also elsewhere on the board
IN2P: U19.8 (IN5P); also elsewhere on the board
IN3N: U19.9 (IN4N); also elsewhere on the board
IN3P: U19.10 (IN4P); also elsewhere on the board
IN4N: U19.11 (IN3N); also elsewhere on the board
IN4P: U19.12 (IN3P); also elsewhere on the board
IN5N: U19.13 (IN2N); also elsewhere on the board
IN5P: U19.14 (IN2P); also elsewhere on the board
IN6N: U19.15 (IN1N); also elsewhere on the board
IN6P: U19.16 (IN1P); also elsewhere on the board
IN7N: C280.1, C281.1, R174.1, U19.3 (IN7N)
IN7P: C281.2, C282.1, R175.1, U19.4 (IN7P)
IN8N: C283.1, C284.1, R178.1, U19.1 (IN8N)
IN8P: C284.2, C285.1, R179.1, U19.2 (IN8P)
LED: U18.61 (LED)
LED1: R171.1, U18.33 (41_A17)
LED2: R183.1, U18.32 (40_A16)
MISO1: J4.4, U18.3 (1_TX1_CTX2_MISO1)
MOSI1: J4.5, U18.18 (26_A12_MOSI1)
unnamed: C85.2, C89.2, R51.2
unnamed: C87.1, R50.2, R54.1
unnamed: D1.2 (A), R56.2
unnamed: D2.2 (A), R55.2
unnamed: D3.2 (A), R170.2
unnamed: D4.2 (A), R171.2
unnamed: D5.2 (A), R183.2
unnamed: F2.2, J16.2
unnamed: JP25.2 (B), U19.31 (RESV1)
unnamed: C94.1, U19.28 (VCAP1)
unnamed: C92.1, U19.30 (VCAP2)
unnamed: C276.1, C278.1, U19.55 (VCAP3)
unnamed: C277.1, U19.26 (VCAP4)
unnamed: R57.2, U21.3 (~RESET)
unnamed: C104.1, U22.4 (NR)
unnamed: C105.1, U23.4 (NR)
unnamed: R181.1, R182.2, U56.3 (+)
unnamed: J29.1, U56.1, U56.4 (-)
unnamed: J30.2, U57.3 (+)
unnamed: J31.3, U57.1, U57.4 (-)
R+: U18.60 (R+)
R-: U18.65 (R-)
SCL: J17.2, R59.1, U18.41 (19_A5_SCL), U21.22 (SCL)
SCL1: J7.2, J15.2, J18.2, U18.38 (16_A2_RX4_SCL1)
SCL2: J23.2, U18.16 (24_A10_TX6_SCL2)
SCLK1: J4.3, U18.19 (27_A13_SCK1)
SCL_CH1: R62.1, U21.5 (SC0); also elsewhere on the board
SCL_CH2: R68.1, U21.7 (SC1); also elsewhere on the board
SCL_CH3: R63.1, U21.9 (SC2); also elsewhere on the board
SCL_CH4: R69.1, U21.11 (SC3); also elsewhere on the board
SCL_CH5: R64.1, U21.14 (SC4); also elsewhere on the board
SCL_CH6: R70.1, U21.16 (SC5); also elsewhere on the board
SDA: J17.1, R60.1, U18.40 (18_A4_SDA), U21.23 (SDA)
SDA1: J7.1, J15.1, J18.1, U18.39 (17_A3_TX4_SDA1)
SDA2: J23.1, U18.17 (25_A11_RX6_SDA2)
SDA_CH1: R65.1, U21.4 (SD0); also elsewhere on the board
SDA_CH2: R71.1, U21.6 (SD1); also elsewhere on the board
SDA_CH3: R66.1, U21.8 (SD2); also elsewhere on the board
SDA_CH4: R72.1, U21.10 (SD3); also elsewhere on the board
SDA_CH5: R67.1, U21.13 (SD4); also elsewhere on the board
SDA_CH6: R73.1, U21.15 (SD5); also elsewhere on the board
SRB1: J29.2, J31.2, U19.17 (SRB1)
SRB2: J30.1, U19.18 (SRB2)
T+: U18.63 (T+)
T-: U18.62 (T-)
USB_D+: U18.67 (D+)
USB_D-: U18.66 (D-)
VIN: F2.1, J8.1
VL: C90.1, C102.1, J4.1, J7.3, J15.3, J17.3, J18.3, J20.1, J21.1, J22.1, J23.3, R49.2, R52.2, R53.2, R55.1, R57.1, R59.2, R60.2, R62.2, R63.2, R64.2, R65.2, R66.2, R67.2, R68.2, R69.2, R70.2, R71.2, R72.2, R73.2, U17.5 (VOUT), U19.48 (DVDD), U19.50 (DVDD), U21.24 (VCC); also elsewhere on the board

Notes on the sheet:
Voltajes requeridos: - Alimentación opamps +-5V - Alimentación digipots +-2.5V - Alimentación ADC +-2.5V - Alimentación digital 3.3V
I2C multiplexer
Digital logic supply
ADC
MCU
I2C_CH2
-2.5V power supply
ADDRESS 0x70
SPI_SENSORS
CONNECTORS
POWER SUPPLY
bipolar power supply
Signal Conditioning Channels
Lista de pines necesarios ------------------------- ADC_START MICRO-OUTPUT ADC_DRDY MICRO-INPUT ADC_CLKSEL MICRO-OUTPUT ADC_RST MICRO-OUTPUT ADC_MOSI ADC_MISO ADC_SCK ADC_CS ------------------------ ADC_PWDN MICRO-OUTPUT
I2C_CH1
Passive notch filter
BIAS
+2.5V power supply
ADC_SPI
VIN
I2C_CH0
INPUTS
ADC_CTRL
I2C_SENSORS

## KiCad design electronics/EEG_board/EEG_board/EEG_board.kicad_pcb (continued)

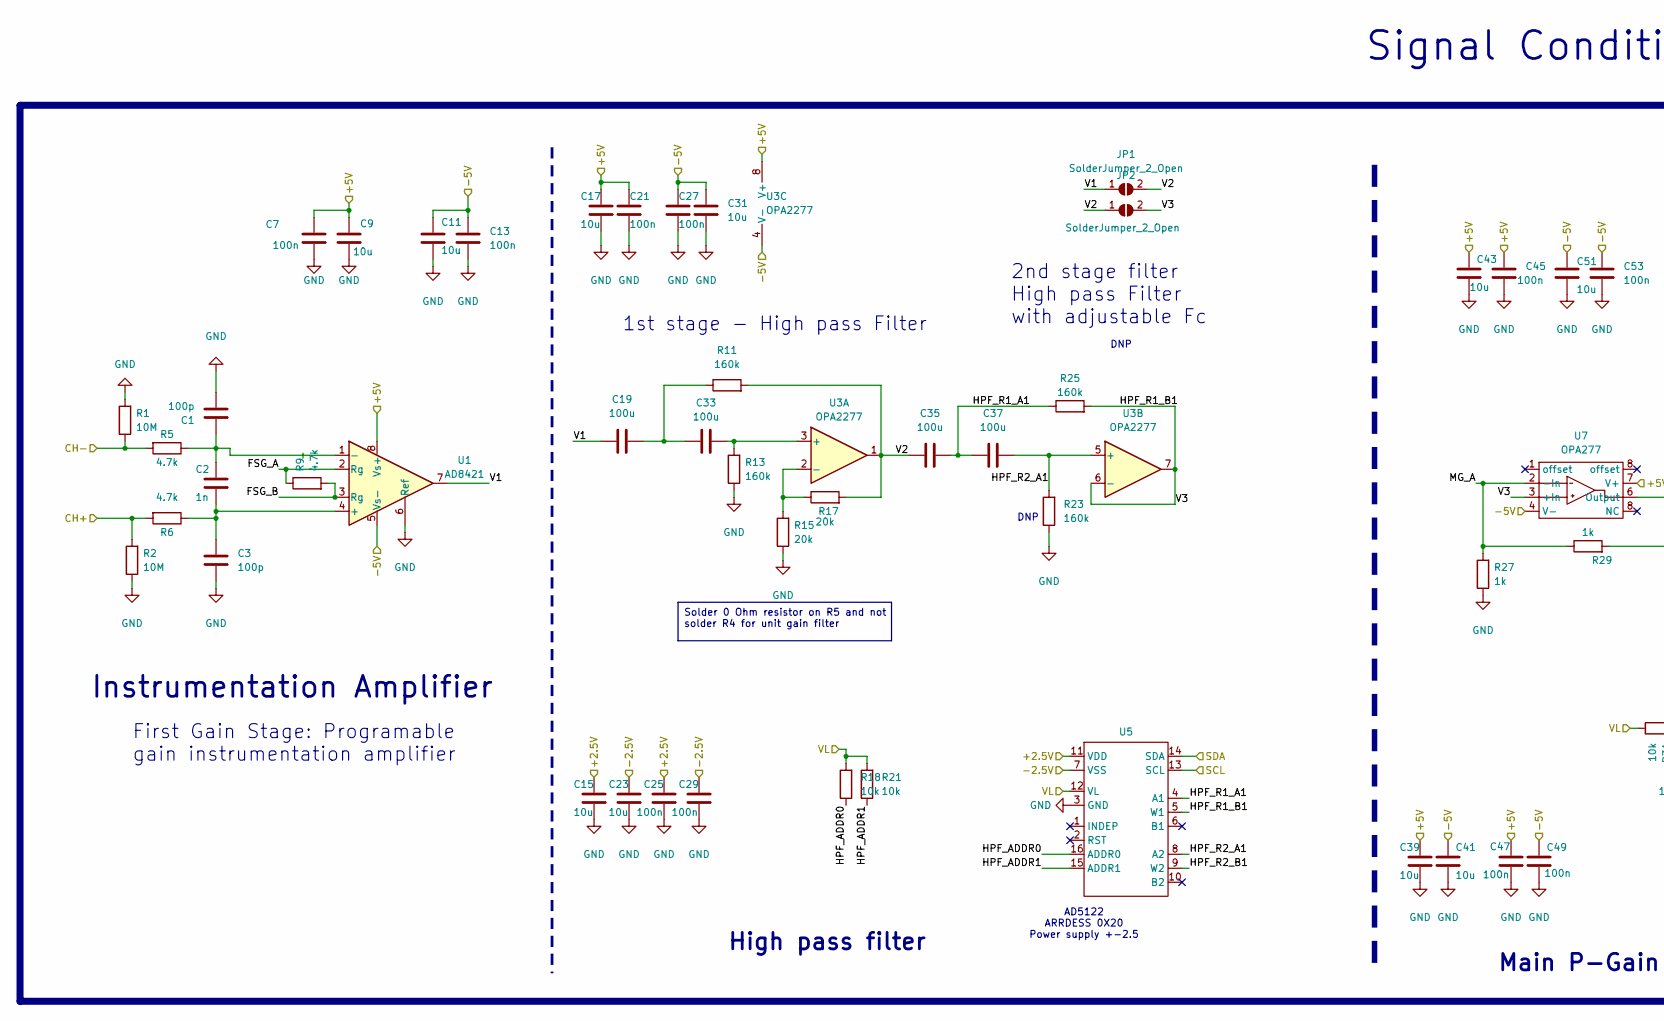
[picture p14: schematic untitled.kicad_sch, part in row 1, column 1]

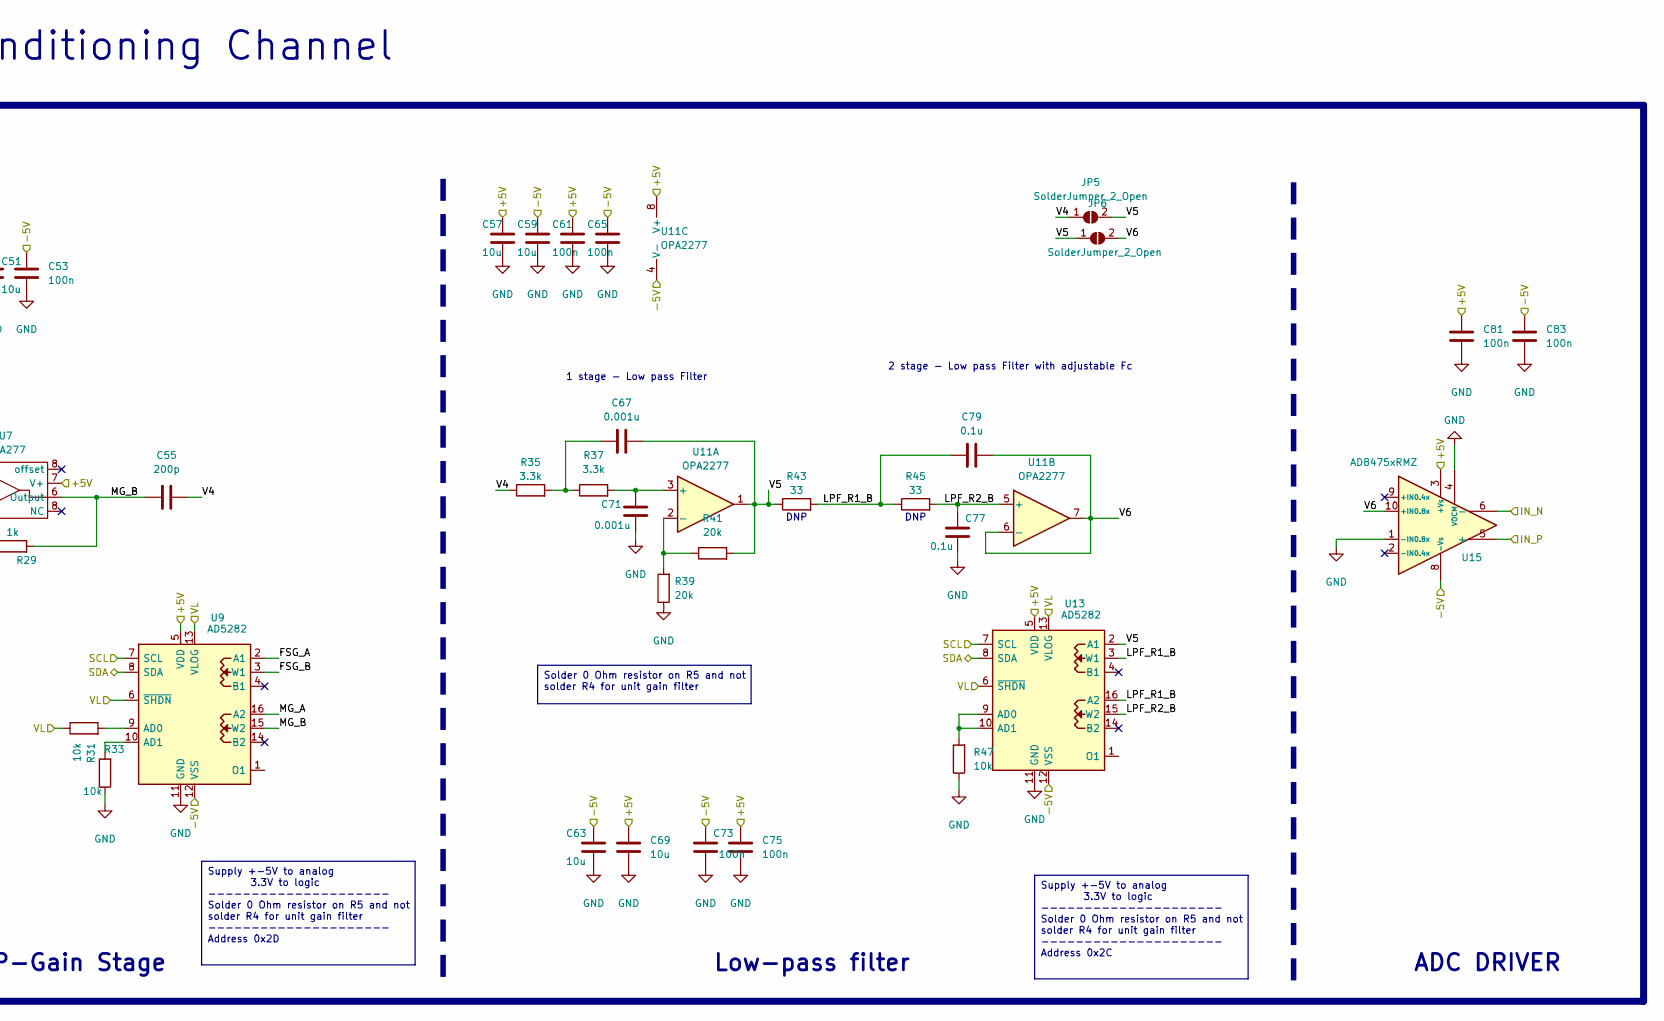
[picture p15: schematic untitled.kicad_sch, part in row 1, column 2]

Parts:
C1, C3: 100p; C_0603_1608Metric
C2: 1n; C_0603_1608Metric
C7, C13, C21, C25, C27, C29, C45, C47, C49, C53, C61, C65, C73, C75, C81, C83: 100n; C_0603_1608Metric
C9, C11, C15, C17, C23, C31, C39, C41, C43, C51, C57, C59, C63, C69: 10u; C_0805_2012Metric
C19, C33, C35, C37: 100u; C_1206_3216Metric
C55: 200p; C_0603_1608Metric
C67, C71: 0.001u; C_0603_1608Metric
C77, C79: 0.1u; C_0603_1608Metric
JP1, JP2, JP5, JP6: SolderJumper_2_Open; SolderJumper-2_P1.3mm_Open_RoundedPad1.0x1.5mm
R1, R2: 10M; R_0603_1608Metric
R5, R6, R9: 4.7k; R_0603_1608Metric
R11, R13, R23, R25: 160k; R_0603_1608Metric
R15, R17, R39, R41: 20k; R_0603_1608Metric
R18, R21, R31, R33, R47: 10k; R_0603_1608Metric
R27, R29: 1k; R_0603_1608Metric
R35, R37: 3.3k; R_0603_1608Metric
R43, R45: 33; R_0603_1608Metric
U1: AD8421; SOIC-8_3.9x4.9mm_P1.27mm
U3, U11: OPA2277; SOIC-8_3.9x4.9mm_P1.27mm
U5: TSSOP-16_4.4x5mm_P0.65mm
U7: OPA277; SOIC-8_3.9x4.9mm_P1.27mm
U9, U13: AD5282; TSSOP-16_4.4x5mm_P0.65mm
U15: AD8475xRMZ; MSOP-10_3x3mm_P0.5mm

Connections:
+2.5V: C15.1, C25.1, U5.11 (VDD); also elsewhere on the board
+5V: C7.1, C9.1, C17.2, C21.1, C39.1, C43.1, C45.1, C47.1, C57.1, C61.1, C69.1, C75.1, C81.1, U1.8 (Vs+), U3.8 (V+), U7.7 (V+), U9.5 (VDD), U11.8 (V+), U13.5 (VDD), U15.3 (+Vs); also elsewhere on the board
-2.5V: C23.1, C29.1, U5.7 (VSS); also elsewhere on the board
-5V: C11.1, C13.1, C27.1, C31.1, C41.1, C49.1, C51.1, C53.1, C59.1, C63.1, C65.1, C73.1, C83.1, U1.5 (Vs-), U3.4 (V-), U7.4 (V-), U9.12 (VSS), U11.4 (V-), U13.12 (VSS), U15.8 (-Vs); also elsewhere on the board
/PPBF_CHANNEL1/FSG_A: R9.1, U1.2 (Rg), U9.2 (A1)
/PPBF_CHANNEL1/FSG_B: R9.2, U1.3 (Rg), U9.3 (W1)
/PPBF_CHANNEL1/HPF_ADDR0: R18.1, U5.16 (ADDR0)
/PPBF_CHANNEL1/HPF_ADDR1: R21.1, U5.15 (ADDR1)
/PPBF_CHANNEL1/HPF_R1_A1: C35.2, C37.1, R25.1, U5.4 (A1)
/PPBF_CHANNEL1/HPF_R1_B1: JP2.2 (B), R25.2, U3.6 (-), U3.7, U5.5 (W1), U7.3 (+In)
/PPBF_CHANNEL1/HPF_R2_A1: C37.2, R23.2, U3.5 (+), U5.8 (A2)
/PPBF_CHANNEL1/HPF_R2_B1: U5.9 (W2)
/PPBF_CHANNEL1/LPF_R1_B: C79.1, R43.2, R45.1, U13.3 (W1), U13.16 (A2)
/PPBF_CHANNEL1/LPF_R2_B: C77.1, R45.2, U11.5 (+), U13.15 (W2)
/PPBF_CHANNEL1/MG_A: R27.2, R29.1, U7.2 (-In), U9.16 (A2)
/PPBF_CHANNEL1/MG_B: C55.1, R29.2, U7.6 (Output), U9.15 (W2)
/PPBF_CHANNEL1/V1: C19.1, JP1.1 (A), U1.7
/PPBF_CHANNEL1/V2: C35.1, JP1.2 (B), JP2.1 (A), R11.2, R17.2, U3.1
/PPBF_CHANNEL1/V4: C55.2, JP5.1 (A), R35.1
/PPBF_CHANNEL1/V5: C67.2, JP5.2 (B), JP6.1 (A), R41.2, R43.1, U11.1, U13.2 (A1)
/PPBF_CHANNEL1/V6: C79.2, JP6.2 (B), U11.6 (-), U11.7, U15.10 (+IN0.8x)
CH2_+: R2.2, R6.2; also elsewhere on the board
CH2_-: R1.1, R5.2; also elsewhere on the board
GND: C1.2, C3.2, C7.2, C9.2, C11.2, C13.2, C15.2, C17.1, C21.2, C23.2, C25.2, C27.2, C29.2, C31.2, C39.2, C41.2, C43.2, C45.2, C47.2, C49.2, C51.2, C53.2, C57.2, C59.2, C61.2, C63.2, C65.2, C69.2, C71.2, C73.2, C75.2, C77.2, C81.2, C83.2, R1.2, R2.1, R13.1, R15.1, R23.1, R27.1, R33.1, R39.1, R47.1, U1.6 (Ref), U5.3 (GND), U9.11 (GND), U13.11 (GND), U15.1 (-IN0.8x), U15.4 (VOCM); also elsewhere on the board
IN2N: U15.6 (-); also elsewhere on the board
IN2P: U15.5 (+); also elsewhere on the board
unnamed: C19.2, C33.1, R11.1
unnamed: C67.1, R35.2, R37.1
unnamed: C2.2, C3.1, R6.1, U1.4 (+)
unnamed: C1.1, C2.1, R5.1, U1.1 (-)
unnamed: C33.2, R13.2, U3.3 (+)
unnamed: R15.2, R17.1, U3.2 (-)
unnamed: R31.2, U9.9 (AD0)
unnamed: R33.2, U9.10 (AD1)
unnamed: C71.1, R37.2, U11.3 (+)
unnamed: R39.2, R41.1, U11.2 (-)
unnamed: R47.2, U13.9 (AD0), U13.10 (AD1)
SCL_CH2: U5.13 (SCL), U9.7 (SCL), U13.7 (SCL); also elsewhere on the board
SDA_CH2: U5.14 (SDA), U9.8 (SDA), U13.8 (SDA); also elsewhere on the board
VL: R18.2, R21.2, R31.1, U5.12 (VL), U9.6 (~SHDN), U9.13 (VLOG), U13.6 (~SHDN), U13.13 (VLOG); also elsewhere on the board

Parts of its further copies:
C4, C6, C108, C110, C150, C152, C192, C194, C234, C236: 100p; C_0603_1608Metric
C5, C109, C151, C193, C235: 1n; C_0603_1608Metric
C8, C10, C16, C18, C22, C24, C40, C42, C46, C50, C58, C60, C70, C72, C112, C113, C115, C116, C119, C123, C127, C128, C129, C133, C136, C137, C139, C142, C154, C155, C157, C158, C161, C165, C169, C170, C171, C175, C178, C179, C181, C184, C196, C197, C199, C200, C203, C207, C211, C212, C213, C217, C220, C221, C223, C226, C238, C239, C241, C242, C245, C249, C253, C254, C255, C259, C262, C263, C265, C268: 10u; C_0805_2012Metric
C12, C14, C26, C30, C32, C34, C44, C48, C52, C54, C64, C68, C74, C76, C82, C84, C111, C114, C118, C120, C121, C122, C130, C131, C132, C134, C138, C140, C144, C145, C148, C149, C153, C156, C160, C162, C163, C164, C172, C173, C174, C176, C180, C182, C186, C187, C190, C191, C195, C198, C202, C204, C205, C206, C214, C215, C216, C218, C222, C224, C228, C229, C232, C233, C237, C240, C244, C246, C247, C248, C256, C257, C258, C260, C264, C266, C270, C271, C274, C275: 100n; C_0603_1608Metric
C20, C28, C36, C38, C117, C124, C125, C126, C159, C166, C167, C168, C201, C208, C209, C210, C243, C250, C251, C252: 100u; C_1206_3216Metric
C56, C135, C177, C219, C261: 200p; C_0603_1608Metric
C62, C66, C141, C143, C183, C185, C225, C227, C267, C269: 0.001u; C_0603_1608Metric
C78, C80, C146, C147, C188, C189, C230, C231, C272, C273: 0.1u; C_0603_1608Metric
JP3, JP4, JP7, JP8, JP9, JP10, JP11, JP12, JP13, JP14, JP15, JP16, JP17, JP18, JP19, JP20, JP21, JP22, JP23, JP24: SolderJumper_2_Open; SolderJumper-2_P1.3mm_Open_RoundedPad1.0x1.5mm
R3, R4, R74, R75, R98, R99, R122, R123, R146, R147: 10M; R_0603_1608Metric
R7, R8, R10, R76, R77, R78, R100, R101, R102, R124, R125, R126, R148, R149, R150: 4.7k; R_0603_1608Metric
R12, R16, R24, R26, R79, R80, R85, R86, R103, R104, R109, R110, R127, R128, R133, R134, R151, R152, R157, R158: 160k; R_0603_1608Metric
R14, R19, R40, R42, R81, R82, R93, R94, R105, R106, R117, R118, R129, R130, R141, R142, R153, R154, R165, R166: 20k; R_0603_1608Metric
R20, R22, R32, R34, R48, R83, R84, R89, R90, R97, R107, R108, R113, R114, R121, R131, R132, R137, R138, R145, R155, R156, R161, R162, R169: 10k; R_0603_1608Metric
R28, R30, R87, R88, R111, R112, R135, R136, R159, R160: 1k; R_0603_1608Metric
R36, R38, R91, R92, R115, R116, R139, R140, R163, R164: 3.3k; R_0603_1608Metric
R44, R46, R95, R96, R119, R120, R143, R144, R167, R168: 33; R_0603_1608Metric
U2, U24, U32, U40, U48: AD8421; SOIC-8_3.9x4.9mm_P1.27mm
U4, U12, U25, U29, U33, U37, U41, U45, U49, U53: OPA2277; SOIC-8_3.9x4.9mm_P1.27mm
U6, U26, U34, U42, U50: TSSOP-16_4.4x5mm_P0.65mm
U8, U27, U35, U43, U51: OPA277; SOIC-8_3.9x4.9mm_P1.27mm
U10, U14, U28, U30, U36, U38, U44, U46, U52, U54: AD5282; TSSOP-16_4.4x5mm_P0.65mm
U16, U31, U39, U47, U55: AD8475xRMZ; MSOP-10_3x3mm_P0.5mm

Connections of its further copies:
+2.5V: C18.1, C30.1, C115.1, C120.1, C157.1, C162.1, C199.1, C204.1, C241.1, C246.1, U6.11 (VDD), U26.11 (VDD), U34.11 (VDD), U42.11 (VDD), U50.11 (VDD); also elsewhere on the board
+5V: C8.1, C12.1, C16.2, C26.1, C40.1, C44.1, C46.1, C52.1, C58.1, C64.1, C72.1, C76.1, C82.1, C111.1, C112.1, C116.2, C118.1, C127.1, C129.1, C130.1, C131.1, C136.1, C138.1, C142.1, C145.1, C148.1, C153.1, C154.1, C158.2, C160.1, C169.1, C171.1, C172.1, C173.1, C178.1, C180.1, C184.1, C187.1, C190.1, C195.1, C196.1, C200.2, C202.1, C211.1, C213.1, C214.1, C215.1, C220.1, C222.1, C226.1, C229.1, C232.1, C237.1, C238.1, C242.2, C244.1, C253.1, C255.1, C256.1, C257.1, C262.1, C264.1, C268.1, C271.1, C274.1, U2.8 (Vs+), U4.8 (V+), U8.7 (V+), U10.5 (VDD), U12.8 (V+), U14.5 (VDD), U16.3 (+Vs), U24.8 (Vs+), U25.8 (V+), U27.7 (V+), U28.5 (VDD), U29.8 (V+), U30.5 (VDD), U31.3 (+Vs), U32.8 (Vs+), U33.8 (V+), U35.7 (V+), U36.5 (VDD), U37.8 (V+), U38.5 (VDD), U39.3 (+Vs), U40.8 (Vs+), U41.8 (V+), U43.7 (V+), U44.5 (VDD), U45.8 (V+), U46.5 (VDD), U47.3 (+Vs), U48.8 (Vs+), U49.8 (V+), U51.7 (V+), U52.5 (VDD), U53.8 (V+), U54.5 (VDD), U55.3 (+Vs); also elsewhere on the board
-2.5V: C24.1, C34.1, C119.1, C122.1, C161.1, C164.1, C203.1, C206.1, C245.1, C248.1, U6.7 (VSS), U26.7 (VSS), U34.7 (VSS), U42.7 (VSS), U50.7 (VSS); also elsewhere on the board
-5V: C10.1, C14.1, C22.1, C32.1, C42.1, C48.1, C50.1, C54.1, C60.1, C68.1, C70.1, C74.1, C84.1, C113.1, C114.1, C121.1, C123.1, C128.1, C132.1, C133.1, C134.1, C137.1, C139.1, C140.1, C144.1, C149.1, C155.1, C156.1, C163.1, C165.1, C170.1, C174.1, C175.1, C176.1, C179.1, C181.1, C182.1, C186.1, C191.1, C197.1, C198.1, C205.1, C207.1, C212.1, C216.1, C217.1, C218.1, C221.1, C223.1, C224.1, C228.1, C233.1, C239.1, C240.1, C247.1, C249.1, C254.1, C258.1, C259.1, C260.1, C263.1, C265.1, C266.1, C270.1, C275.1, U2.5 (Vs-), U4.4 (V-), U8.4 (V-), U10.12 (VSS), U12.4 (V-), U14.12 (VSS), U16.8 (-Vs), U24.5 (Vs-), U25.4 (V-), U27.4 (V-), U28.12 (VSS), U29.4 (V-), U30.12 (VSS), U31.8 (-Vs), U32.5 (Vs-), U33.4 (V-), U35.4 (V-), U36.12 (VSS), U37.4 (V-), U38.12 (VSS), U39.8 (-Vs), U40.5 (Vs-), U41.4 (V-), U43.4 (V-), U44.12 (VSS), U45.4 (V-), U46.12 (VSS), U47.8 (-Vs), U48.5 (Vs-), U49.4 (V-), U51.4 (V-), U52.12 (VSS), U53.4 (V-), U54.12 (VSS), U55.8 (-Vs); also elsewhere on the board
/PPBF_CHANNEL2/FSG_A: R78.1, U24.2 (Rg), U28.2 (A1)
/PPBF_CHANNEL2/FSG_B: R78.2, U24.3 (Rg), U28.3 (W1)
/PPBF_CHANNEL2/HPF_ADDR0: R83.1, U26.16 (ADDR0)
/PPBF_CHANNEL2/HPF_ADDR1: R84.1, U26.15 (ADDR1)
/PPBF_CHANNEL2/HPF_R1_A1: C125.2, C126.1, R86.1, U26.4 (A1)
/PPBF_CHANNEL2/HPF_R1_B1: JP10.2 (B), R86.2, U25.6 (-), U25.7, U26.5 (W1), U27.3 (+In)
/PPBF_CHANNEL2/HPF_R2_A1: C126.2, R85.2, U25.5 (+), U26.8 (A2)
/PPBF_CHANNEL2/HPF_R2_B1: U26.9 (W2)
/PPBF_CHANNEL2/LPF_R1_B: C147.1, R95.2, R96.1, U30.3 (W1), U30.16 (A2)
/PPBF_CHANNEL2/LPF_R2_B: C146.1, R96.2, U29.5 (+), U30.15 (W2)
/PPBF_CHANNEL2/MG_A: R87.2, R88.1, U27.2 (-In), U28.16 (A2)
/PPBF_CHANNEL2/MG_B: C135.1, R88.2, U27.6 (Output), U28.15 (W2)
/PPBF_CHANNEL2/V1: C117.1, JP9.1 (A), U24.7
/PPBF_CHANNEL2/V2: C125.1, JP9.2 (B), JP10.1 (A), R79.2, R82.2, U25.1
/PPBF_CHANNEL2/V4: C135.2, JP11.1 (A), R91.1
/PPBF_CHANNEL2/V5: C141.2, JP11.2 (B), JP12.1 (A), R94.2, R95.1, U29.1, U30.2 (A1)
/PPBF_CHANNEL2/V6: C147.2, JP12.2 (B), U29.6 (-), U29.7, U31.10 (+IN0.8x)
/PPBF_CHANNEL3/FSG_A: R102.1, U32.2 (Rg), U36.2 (A1)
/PPBF_CHANNEL3/FSG_B: R102.2, U32.3 (Rg), U36.3 (W1)
/PPBF_CHANNEL3/HPF_ADDR0: R107.1, U34.16 (ADDR0)
/PPBF_CHANNEL3/HPF_ADDR1: R108.1, U34.15 (ADDR1)
/PPBF_CHANNEL3/HPF_R1_A1: C167.2, C168.1, R110.1, U34.4 (A1)
/PPBF_CHANNEL3/HPF_R1_B1: JP14.2 (B), R110.2, U33.6 (-), U33.7, U34.5 (W1), U35.3 (+In)
/PPBF_CHANNEL3/HPF_R2_A1: C168.2, R109.2, U33.5 (+), U34.8 (A2)
/PPBF_CHANNEL3/HPF_R2_B1: U34.9 (W2)
/PPBF_CHANNEL3/LPF_R1_B: C189.1, R119.2, R120.1, U38.3 (W1), U38.16 (A2)
/PPBF_CHANNEL3/LPF_R2_B: C188.1, R120.2, U37.5 (+), U38.15 (W2)
/PPBF_CHANNEL3/MG_A: R111.2, R112.1, U35.2 (-In), U36.16 (A2)
/PPBF_CHANNEL3/MG_B: C177.1, R112.2, U35.6 (Output), U36.15 (W2)
/PPBF_CHANNEL3/V1: C159.1, JP13.1 (A), U32.7
/PPBF_CHANNEL3/V2: C167.1, JP13.2 (B), JP14.1 (A), R103.2, R106.2, U33.1
/PPBF_CHANNEL3/V4: C177.2, JP15.1 (A), R115.1
/PPBF_CHANNEL3/V5: C183.2, JP15.2 (B), JP16.1 (A), R118.2, R119.1, U37.1, U38.2 (A1)
/PPBF_CHANNEL3/V6: C189.2, JP16.2 (B), U37.6 (-), U37.7, U39.10 (+IN0.8x)
/PPBF_CHANNEL4/FSG_A: R126.1, U40.2 (Rg), U44.2 (A1)
/PPBF_CHANNEL4/FSG_B: R126.2, U40.3 (Rg), U44.3 (W1)
/PPBF_CHANNEL4/HPF_ADDR0: R131.1, U42.16 (ADDR0)
/PPBF_CHANNEL4/HPF_ADDR1: R132.1, U42.15 (ADDR1)
/PPBF_CHANNEL4/HPF_R1_A1: C209.2, C210.1, R134.1, U42.4 (A1)
/PPBF_CHANNEL4/HPF_R1_B1: JP18.2 (B), R134.2, U41.6 (-), U41.7, U42.5 (W1), U43.3 (+In)
/PPBF_CHANNEL4/HPF_R2_A1: C210.2, R133.2, U41.5 (+), U42.8 (A2)
/PPBF_CHANNEL4/HPF_R2_B1: U42.9 (W2)
/PPBF_CHANNEL4/LPF_R1_B: C231.1, R143.2, R144.1, U46.3 (W1), U46.16 (A2)
/PPBF_CHANNEL4/LPF_R2_B: C230.1, R144.2, U45.5 (+), U46.15 (W2)
/PPBF_CHANNEL4/MG_A: R135.2, R136.1, U43.2 (-In), U44.16 (A2)
/PPBF_CHANNEL4/MG_B: C219.1, R136.2, U43.6 (Output), U44.15 (W2)
/PPBF_CHANNEL4/V1: C201.1, JP17.1 (A), U40.7
/PPBF_CHANNEL4/V2: C209.1, JP17.2 (B), JP18.1 (A), R127.2, R130.2, U41.1
/PPBF_CHANNEL4/V4: C219.2, JP19.1 (A), R139.1
/PPBF_CHANNEL4/V5: C225.2, JP19.2 (B), JP20.1 (A), R142.2, R143.1, U45.1, U46.2 (A1)
/PPBF_CHANNEL4/V6: C231.2, JP20.2 (B), U45.6 (-), U45.7, U47.10 (+IN0.8x)
/PPBF_CHANNEL5/FSG_A: R150.1, U48.2 (Rg), U52.2 (A1)
/PPBF_CHANNEL5/FSG_B: R150.2, U48.3 (Rg), U52.3 (W1)
/PPBF_CHANNEL5/HPF_ADDR0: R155.1, U50.16 (ADDR0)
/PPBF_CHANNEL5/HPF_ADDR1: R156.1, U50.15 (ADDR1)
/PPBF_CHANNEL5/HPF_R1_A1: C251.2, C252.1, R158.1, U50.4 (A1)
/PPBF_CHANNEL5/HPF_R1_B1: JP22.2 (B), R158.2, U49.6 (-), U49.7, U50.5 (W1), U51.3 (+In)
/PPBF_CHANNEL5/HPF_R2_A1: C252.2, R157.2, U49.5 (+), U50.8 (A2)
/PPBF_CHANNEL5/HPF_R2_B1: U50.9 (W2)
/PPBF_CHANNEL5/LPF_R1_B: C273.1, R167.2, R168.1, U54.3 (W1), U54.16 (A2)
/PPBF_CHANNEL5/LPF_R2_B: C272.1, R168.2, U53.5 (+), U54.15 (W2)
/PPBF_CHANNEL5/MG_A: R159.2, R160.1, U51.2 (-In), U52.16 (A2)
/PPBF_CHANNEL5/MG_B: C261.1, R160.2, U51.6 (Output), U52.15 (W2)
/PPBF_CHANNEL5/V1: C243.1, JP21.1 (A), U48.7
/PPBF_CHANNEL5/V2: C251.1, JP21.2 (B), JP22.1 (A), R151.2, R154.2, U49.1
/PPBF_CHANNEL5/V4: C261.2, JP23.1 (A), R163.1
/PPBF_CHANNEL5/V5: C267.2, JP23.2 (B), JP24.1 (A), R166.2, R167.1, U53.1, U54.2 (A1)
/PPBF_CHANNEL5/V6: C273.2, JP24.2 (B), U53.6 (-), U53.7, U55.10 (+IN0.8x)
/PPBF_CHANNEL/FSG_A: R10.1, U2.2 (Rg), U10.2 (A1)
/PPBF_CHANNEL/FSG_B: R10.2, U2.3 (Rg), U10.3 (W1)
/PPBF_CHANNEL/HPF_ADDR0: R20.1, U6.16 (ADDR0)
/PPBF_CHANNEL/HPF_ADDR1: R22.1, U6.15 (ADDR1)
/PPBF_CHANNEL/HPF_R1_A1: C36.2, C38.1, R26.1, U6.4 (A1)
/PPBF_CHANNEL/HPF_R1_B1: JP4.2 (B), R26.2, U4.6 (-), U4.7, U6.5 (W1), U8.3 (+In)
/PPBF_CHANNEL/HPF_R2_A1: C38.2, R24.2, U4.5 (+), U6.8 (A2)
/PPBF_CHANNEL/HPF_R2_B1: U6.9 (W2)
/PPBF_CHANNEL/LPF_R1_B: C80.1, R44.2, R46.1, U14.3 (W1), U14.16 (A2)
/PPBF_CHANNEL/LPF_R2_B: C78.1, R46.2, U12.5 (+), U14.15 (W2)
/PPBF_CHANNEL/MG_A: R28.2, R30.1, U8.2 (-In), U10.16 (A2)
/PPBF_CHANNEL/MG_B: C56.1, R30.2, U8.6 (Output), U10.15 (W2)
/PPBF_CHANNEL/V1: C20.1, JP3.1 (A), U2.7
/PPBF_CHANNEL/V2: C36.1, JP3.2 (B), JP4.1 (A), R16.2, R19.2, U4.1
/PPBF_CHANNEL/V4: C56.2, JP7.1 (A), R36.1
/PPBF_CHANNEL/V5: C66.2, JP7.2 (B), JP8.1 (A), R42.2, R44.1, U12.1, U14.2 (A1)
/PPBF_CHANNEL/V6: C80.2, JP8.2 (B), U12.6 (-), U12.7, U16.10 (+IN0.8x)
CH1_+: R4.2, R8.2; also elsewhere on the board
CH1_-: R3.1, R7.2; also elsewhere on the board
CH3_+: R75.2, R77.2; also elsewhere on the board
CH3_-: R74.1, R76.2; also elsewhere on the board
CH4_+: R99.2, R101.2; also elsewhere on the board
CH4_-: R98.1, R100.2; also elsewhere on the board
CH5_+: R123.2, R125.2; also elsewhere on the board
CH5_-: R122.1, R124.2; also elsewhere on the board
CH6_+: R147.2, R149.2; also elsewhere on the board
CH6_-: R146.1, R148.2; also elsewhere on the board
GND: C4.2, C6.2, C8.2, C10.2, C12.2, C14.2, C16.1, C18.2, C22.2, C24.2, C26.2, C30.2, C32.2, C34.2, C40.2, C42.2, C44.2, C46.2, C48.2, C50.2, C52.2, C54.2, C58.2, C60.2, C62.2, C64.2, C68.2, C70.2, C72.2, C74.2, C76.2, C78.2, C82.2, C84.2, C108.2, C110.2, C111.2, C112.2, C113.2, C114.2, C115.2, C116.1, C118.2, C119.2, C120.2, C121.2, C122.2, C123.2, C127.2, C128.2, C129.2, C130.2, C131.2, C132.2, C133.2, C134.2, C136.2, C137.2, C138.2, C139.2, C140.2, C142.2, C143.2, C144.2, C145.2, C146.2, C148.2, C149.2, C150.2, C152.2, C153.2, C154.2, C155.2, C156.2, C157.2, C158.1, C160.2, C161.2, C162.2, C163.2, C164.2, C165.2, C169.2, C170.2, C171.2, C172.2, C173.2, C174.2, C175.2, C176.2, C178.2, C179.2, C180.2, C181.2, C182.2, C184.2, C185.2, C186.2, C187.2, C188.2, C190.2, C191.2, C192.2, C194.2, C195.2, C196.2, C197.2, C198.2, C199.2, C200.1, C202.2, C203.2, C204.2, C205.2, C206.2, C207.2, C211.2, C212.2, C213.2, C214.2, C215.2, C216.2, C217.2, C218.2, C220.2, C221.2, C222.2, C223.2, C224.2, C226.2, C227.2, C228.2, C229.2, C230.2, C232.2, C233.2, C234.2, C236.2, C237.2, C238.2, C239.2, C240.2, C241.2, C242.1, C244.2, C245.2, C246.2, C247.2, C248.2, C249.2, C253.2, C254.2, C255.2, C256.2, C257.2, C258.2, C259.2, C260.2, C262.2, C263.2, C264.2, C265.2, C266.2, C268.2, C269.2, C270.2, C271.2, C272.2, C274.2, C275.2, R3.2, R4.1, R12.1, R14.1, R24.1, R28.1, R34.1, R40.1, R48.1, R74.2, R75.1, R80.1, R81.1, R85.1, R87.1, R90.1, R93.1, R97.1, R98.2, R99.1, R104.1, R105.1, R109.1, R111.1, R114.1, R117.1, R121.1, R122.2, R123.1, R128.1, R129.1, R133.1, R135.1, R138.1, R141.1, R145.1, R146.2, R147.1, R152.1, R153.1, R157.1, R159.1, R162.1, R165.1, R169.1, U2.6 (Ref), U6.3 (GND), U10.11 (GND), U14.11 (GND), U16.1 (-IN0.8x), U16.4 (VOCM), U24.6 (Ref), U26.3 (GND), U28.11 (GND), U30.11 (GND), U31.1 (-IN0.8x), U31.4 (VOCM), U32.6 (Ref), U34.3 (GND), U36.11 (GND), U38.11 (GND), U39.1 (-IN0.8x), U39.4 (VOCM), U40.6 (Ref), U42.3 (GND), U44.11 (GND), U46.11 (GND), U47.1 (-IN0.8x), U47.4 (VOCM), U48.6 (Ref), U50.3 (GND), U52.11 (GND), U54.11 (GND), U55.1 (-IN0.8x), U55.4 (VOCM); also elsewhere on the board
IN1N: U16.6 (-); also elsewhere on the board
IN1P: U16.5 (+); also elsewhere on the board
IN3N: U31.6 (-); also elsewhere on the board
IN3P: U31.5 (+); also elsewhere on the board
IN4N: U39.6 (-); also elsewhere on the board
IN4P: U39.5 (+); also elsewhere on the board
IN5N: U47.6 (-); also elsewhere on the board
IN5P: U47.5 (+); also elsewhere on the board
IN6N: U55.6 (-); also elsewhere on the board
IN6P: U55.5 (+); also elsewhere on the board
unnamed: C20.2, C28.1, R16.1
unnamed: C66.1, R36.2, R38.1
unnamed: C117.2, C124.1, R79.1
unnamed: C141.1, R91.2, R92.1
unnamed: C159.2, C166.1, R103.1
unnamed: C183.1, R115.2, R116.1
unnamed: C201.2, C208.1, R127.1
unnamed: C225.1, R139.2, R140.1
unnamed: C243.2, C250.1, R151.1
unnamed: C267.1, R163.2, R164.1
unnamed: C5.2, C6.1, R8.1, U2.4 (+)
unnamed: C4.1, C5.1, R7.1, U2.1 (-)
unnamed: C28.2, R12.2, U4.3 (+)
unnamed: R14.2, R19.1, U4.2 (-)
unnamed: R32.2, U10.9 (AD0)
unnamed: R34.2, U10.10 (AD1)
unnamed: C62.1, R38.2, U12.3 (+)
unnamed: R40.2, R42.1, U12.2 (-)
unnamed: R48.2, U14.9 (AD0), U14.10 (AD1)
unnamed: C109.2, C110.1, R77.1, U24.4 (+)
unnamed: C108.1, C109.1, R76.1, U24.1 (-)
unnamed: C124.2, R80.2, U25.3 (+)
unnamed: R81.2, R82.1, U25.2 (-)
unnamed: R89.2, U28.9 (AD0)
unnamed: R90.2, U28.10 (AD1)
unnamed: C143.1, R92.2, U29.3 (+)
unnamed: R93.2, R94.1, U29.2 (-)
unnamed: R97.2, U30.9 (AD0), U30.10 (AD1)
unnamed: C151.2, C152.1, R101.1, U32.4 (+)
unnamed: C150.1, C151.1, R100.1, U32.1 (-)
unnamed: C166.2, R104.2, U33.3 (+)
unnamed: R105.2, R106.1, U33.2 (-)
unnamed: R113.2, U36.9 (AD0)
unnamed: R114.2, U36.10 (AD1)
unnamed: C185.1, R116.2, U37.3 (+)
unnamed: R117.2, R118.1, U37.2 (-)
unnamed: R121.2, U38.9 (AD0), U38.10 (AD1)
unnamed: C193.2, C194.1, R125.1, U40.4 (+)
unnamed: C192.1, C193.1, R124.1, U40.1 (-)
unnamed: C208.2, R128.2, U41.3 (+)
unnamed: R129.2, R130.1, U41.2 (-)
unnamed: R137.2, U44.9 (AD0)
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

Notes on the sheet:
Solder 0 Ohm resistor on R5 and not solder R4 for unit gain filter
Supply +-5V to analog 3.3V to logic --------------------- Solder 0 Ohm resistor on R5 and not solder R4 for unit gain filter --------------------- Address 0x2D
Supply +-5V to analog 3.3V to logic --------------------- Solder 0 Ohm resistor on R5 and not solder R4 for unit gain filter --------------------- Address 0x2C
2nd stage filter High pass Filter with adjustable Fc
Instrumentation Amplifier
DNP
ADC DRIVER
AD5122 ARRDESS 0X20 Power supply +-2.5
Low-pass filter
2 stage - Low pass Filter with adjustable Fc
1 stage - Low pass Filter
First Gain Stage: Programable gain instrumentation amplifier
Signal Conditioning Channel
1st stage - High pass Filter
Main P-Gain Stage
High pass filter

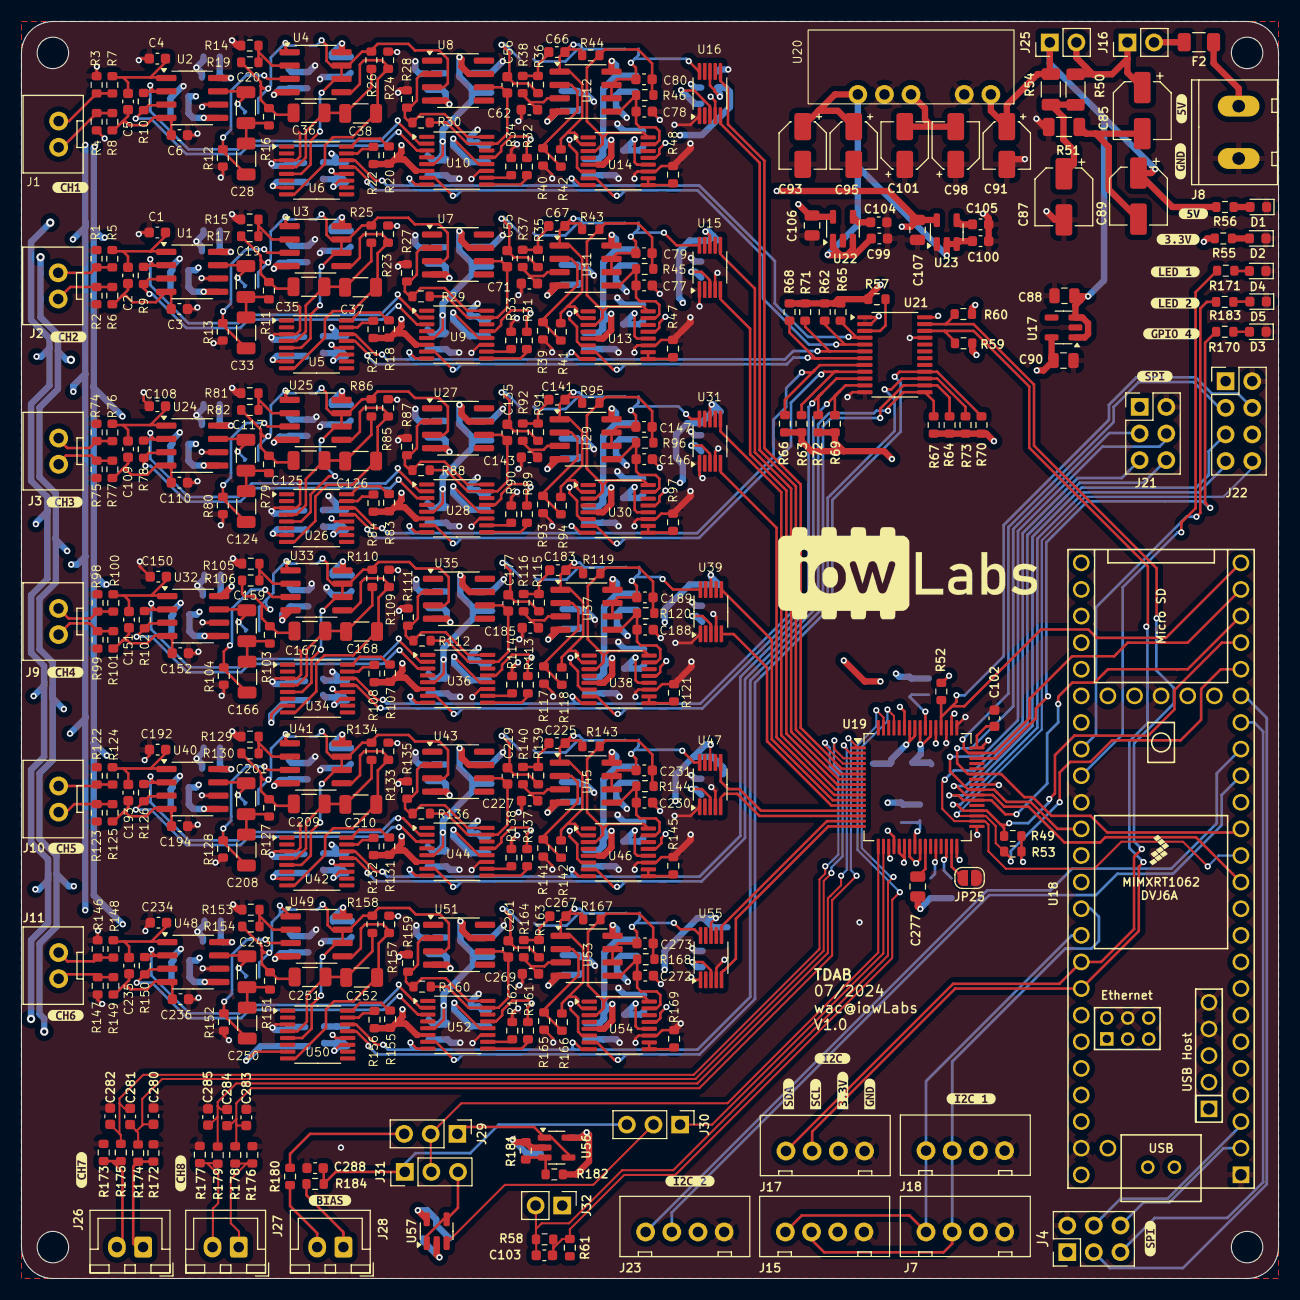
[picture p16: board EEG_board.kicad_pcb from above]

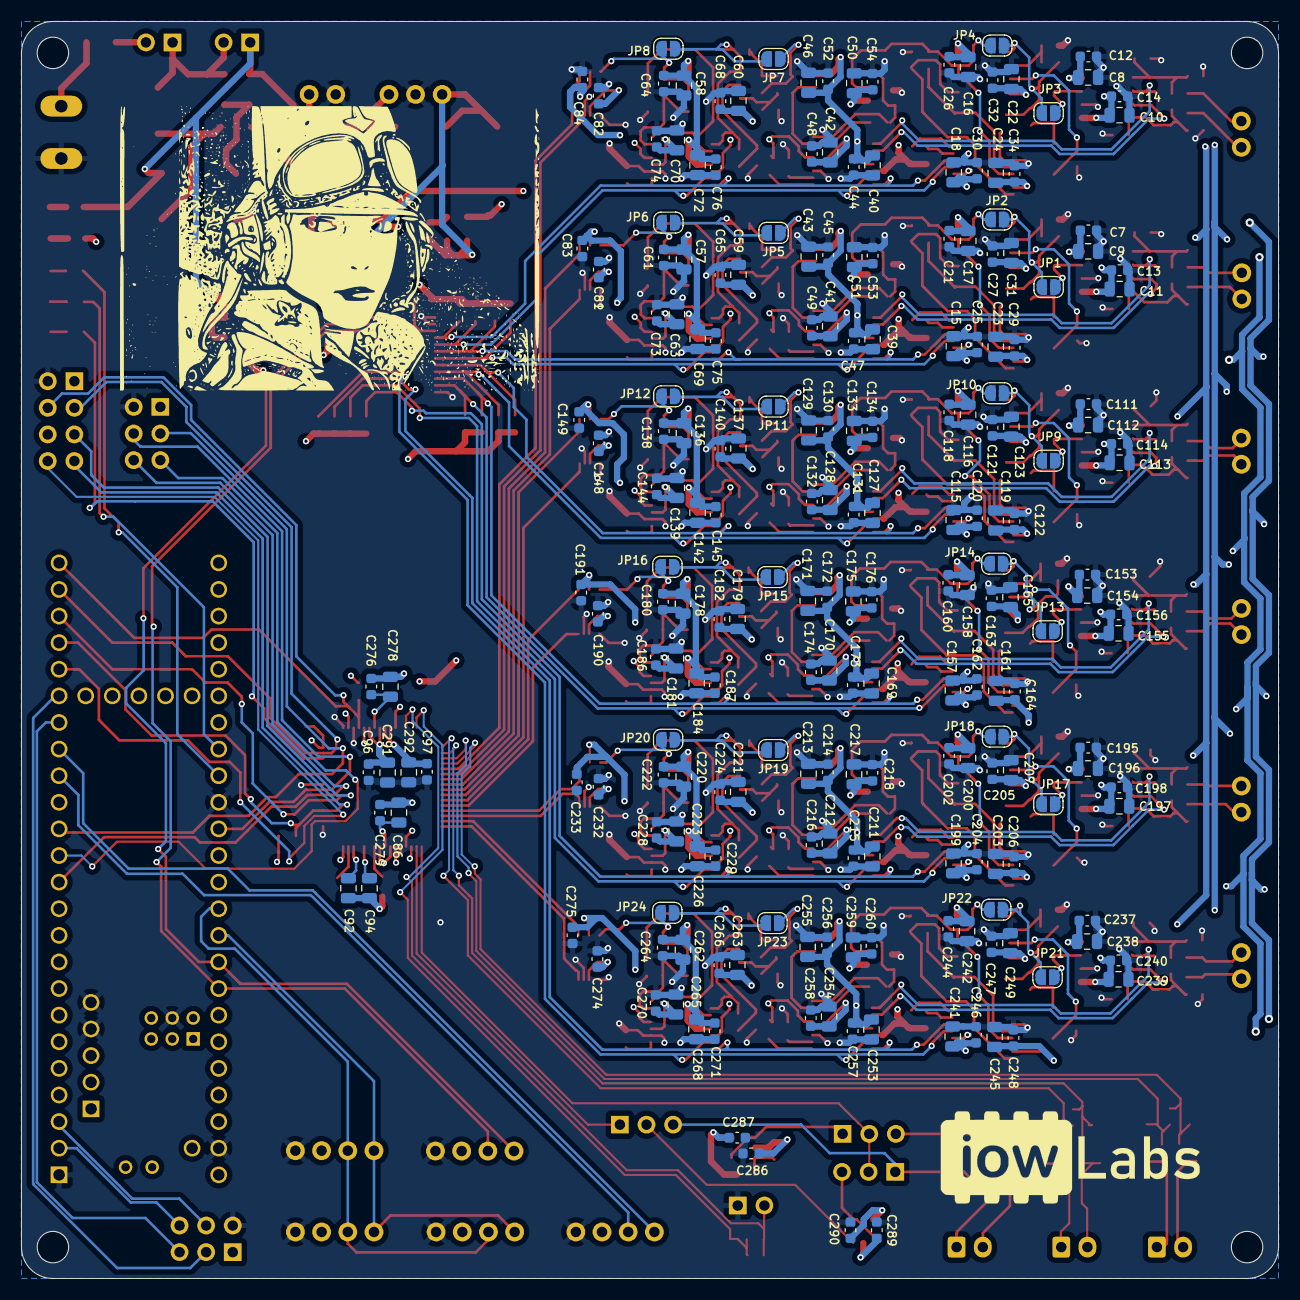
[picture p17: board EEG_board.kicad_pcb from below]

Board: 4 copper layers, 120.0 x 120.0 mm, 613 parts (218 on the bottom side), 266 nets.

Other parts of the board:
kibuzzard-66F1BD5D: G***; kibuzzard-66F1BD5D
kibuzzard-66F1BD73: G***; kibuzzard-66F1BD73
kibuzzard-66F1BE9F: G***; kibuzzard-66F1BE9F
kibuzzard-66F1BE81: G***; kibuzzard-66F1BE81
kibuzzard-66F1BE92: G***; kibuzzard-66F1BE92
kibuzzard-66F1BEAE: G***; kibuzzard-66F1BEAE
kibuzzard-66F1BEC6: G***; kibuzzard-66F1BEC6
kibuzzard-66F1BED1: G***; kibuzzard-66F1BED1
kibuzzard-66F1C1A7: G***; kibuzzard-66F1C1A7
kibuzzard-66F1C1B9: G***; kibuzzard-66F1C1B9
kibuzzard-66F1C1C3: G***; kibuzzard-66F1C1C3
kibuzzard-66F1C1DB: G***; kibuzzard-66F1C1DB
kibuzzard-66F1C1F0: G***; kibuzzard-66F1C1F0
kibuzzard-66F1C19C: G***; kibuzzard-66F1C19C
kibuzzard-66F1C22B: G***; kibuzzard-66F1C22B
kibuzzard-66F1C23E: G***; kibuzzard-66F1C23E
kibuzzard-66F1C29C: G***; kibuzzard-66F1C29C
kibuzzard-66F1C172: G***; kibuzzard-66F1C172
kibuzzard-66F1C187: G***; kibuzzard-66F1C187
kibuzzard-66F1C231: G***; kibuzzard-66F1C231
kibuzzard-66F1C248: G***; kibuzzard-66F1C248
kibuzzard-66F1C256: G***; kibuzzard-66F1C256
kibuzzard-66F1C265: G***; kibuzzard-66F1C265
kibuzzard-66F1C285: G***; kibuzzard-66F1C285
kibuzzard-66F4DE44: G***; kibuzzard-66F4DE44

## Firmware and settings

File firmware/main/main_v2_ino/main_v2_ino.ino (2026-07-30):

#include <Arduino.h>
#include <Wire.h>
#include <IntervalTimer.h>
#include <ArduinoJson.h>
#include <MPU9250_WE.h>


// ======================== CONFIGURACIÓN ========================
#define SAMPLE_RATE_HZ   5000                 // 5 kS/s
#define TABLE_SIZE       1024                 // LUT seno
#define USE_EXTENDED_FRAME 1                  // 0 = compacto (17 B), 1 = extendido (23 B)
#define SERIAL_BAUD      1000000              // se ignora en USB CDC, útil en UART

// Conteos
#define NUM_ADC24  6   // <-- 6 canales ADC de 24 bits
#define NUM_ACC16  6   // 2 IMUs * 3 ejes = 6


// Tamaño frame extendido: 2 + 4 + 6*3 + 6*2 + 2 = 38
#if USE_EXTENDED_FRAME
  #define FRAME_BYTES (2 + 4 + NUM_ADC24*3 + NUM_ACC16*2 + 2)
#else
  #error "Este sketch usa sólo el formato extendido con CRC"
#endif



// Frecuencias de prueba (todas < Nyquist = 2.5 kHz)
static float freq_adc24[NUM_ADC24] = {500, 500, 500, 100, 100, 100};
static float freq_acc16[NUM_ACC16]= { 300.0f, 250.0f, 100.0f, 50.0f, 10.0f, 5.0f };

// Amplitudes (ajusta a gusto)
static const int32_t AMP_24B = 12000; // pico ~2^22 - 1 para 24b signed
static const int16_t AMP_16B = 12000;         // pico para 16b (evita saturar)



// Buffer circular de tramas (SPSC)
#define TX_QUEUE_LEN 2048
static_assert((TX_QUEUE_LEN & (TX_QUEUE_LEN - 1)) == 0, "TX_QUEUE_LEN must be power of two");

// Lote máximo a escribir por iteración (controla monopolio de CPU)
#define MAX_FRAMES_PER_ITER 32



// =================== MPU9250 ====================
MPU9250_WE imu1 = MPU9250_WE(&Wire1,0x68);
MPU9250_WE imu2 = MPU9250_WE(&Wire1,0x69);
bool imu1_ok = false, imu2_ok = false;

// ========================== ESTADOS / CONTROL =======================

enum RunState : uint8_t { IDLE = 0, RUNNING = 1, STOPPED = 2 };
volatile RunState g_state = IDLE;

// Contador de overflows de cola
volatile uint32_t drop_count = 0;

// ======================== GENERADOR SENOIDAL ========================
static float sine_table[TABLE_SIZE];
static float ph_adc24[NUM_ADC24] = {0};
static float ph_acc16[6] = {0};

static float step_adc24[NUM_ADC24];
static float step_acc16[NUM_ACC16];


// ============================ TX QUEUE ==============================
static uint8_t tx_queue[TX_QUEUE_LEN][FRAME_BYTES];
volatile uint16_t q_write = 0;
volatile uint16_t q_read  = 0;


// ========================== TIMER / CONTADORES ======================
IntervalTimer sampler;
volatile uint32_t sample_id = 0;

// ====================== CRC16 (para extendido) =================
static uint16_t crc16_ccitt(const uint8_t* data, size_t len) {
  uint16_t crc = 0xFFFF;
  for (size_t i = 0; i < len; i++) {
    crc ^= (uint16_t)data[i] << 8;
    for (int j = 0; j < 8; j++) {
      if (crc & 0x8000) crc = (crc << 1) ^ 0x1021;
      else              crc = (crc << 1);
    }
  }
  return crc;
}

// ====================== EMPAQUE 24-bit LE ======================
static inline void pack_s24_le(int32_t val, uint8_t* out) {
  // saturar a 24 bits signed
  if (val >  0x7FFFFF) val =  0x7FFFFF;
  if (val < -0x800000) val = -0x800000;
  // little-endian 24b (2's complement)
  out[0] = (uint8_t)(val & 0xFF);
  out[1] = (uint8_t)((val >> 8) & 0xFF);
  out[2] = (uint8_t)((val >> 16) & 0xFF);
}

// ====================== ISR: PRODUCE UNA TRAMA =================
void isr_sample() {
if (g_state != RUNNING) return;

  uint16_t next_w = (q_write + 1) & (TX_QUEUE_LEN - 1);
  if (next_w == q_read) { drop_count++; return; }

  uint8_t* f = tx_queue[q_write];
  uint32_t off = 0;

  // Header
  f[0] = 0xA5; f[1] = 0x5A; off = 2;

  // sample_id LE
  uint32_t sid = sample_id;
  f[off+0] = (uint8_t)(sid & 0xFF);
  f[off+1] = (uint8_t)((sid>>8) & 0xFF);
  f[off+2] = (uint8_t)((sid>>16) & 0xFF);
  f[off+3] = (uint8_t)((sid>>24) & 0xFF);
  off += 4;

  // 6× ADC24 (s24 LE)
  for (int i=0;i<NUM_ADC24;++i) {
    int32_t s = (int32_t)lrintf(AMP_24B * sine_table[(int)ph_adc24[i]]);
    pack_s24_le(s, &f[off]); off += 3;
  }

  // 6× ACC16 (int16 LE)
  // Leer cada muestra (o cada N si quieres aligerar)
  //if (imu1_ok && (sample_id % 5 == 0)) imu1.readSensor();
  //if (imu2_ok && (sample_id % 5 == 0)) imu2.readSensor();

  for (int i=0;i<NUM_ACC16;i++) {
    int16_t s = 0;

    if (imu1_ok && i < 3) {
      auto g=imu1.getGValues();
      if (i==0) s = (int16_t)(g.x*10000);
      if (i==1) s = (int16_t)(g.y*10000);
      if (i==2) s = (int16_t)(g.z*10000);
    }
    else if (imu2_ok && i >=3 && i<6) {
      auto g=imu2.getGValues();
      if (i==3) s = (int16_t)(g.x*10000);
      if (i==4) s = (int16_t)(g.y*10000);
      if (i==5) s = (int16_t)(g.z*10000);
    }
    else {
      // Dummy
      s = (int16_t)lrintf(AMP_16B * sine_table[(int)ph_acc16[i]]);
    }

    f[off+0]=(uint8_t)(s & 0xFF);
    f[off+1]=(uint8_t)((s>>8)&0xFF);
    off+=2;
  }

  // CRC16
  uint16_t crc = crc16_ccitt(f, off);
  f[off+0] = (uint8_t)(crc >> 8);
  f[off+1] = (uint8_t)(crc & 0xFF);
  off += 2;

  // Avance de fases
  for (int i=0;i<NUM_ADC24;++i) {
    ph_adc24[i] += step_adc24[i];
    if (ph_adc24[i] >= TABLE_SIZE) ph_adc24[i] -= TABLE_SIZE;
  }
  for (int i=0;i<NUM_ACC16;++i) {
    ph_acc16[i] += step_acc16[i];
    if (ph_acc16[i] >= TABLE_SIZE) ph_acc16[i] -= TABLE_SIZE;
  }

  q_write = next_w;
  sample_id++;
}
// ====================== UTIL: actualizar pasos ======================
static void update_phase_steps() {
  for (int i=0;i<NUM_ADC24;++i)
    step_adc24[i] = (freq_adc24[i] / SAMPLE_RATE_HZ) * TABLE_SIZE;
  for (int i=0;i<NUM_ACC16;++i)
    step_acc16[i] = (freq_acc16[i] / SAMPLE_RATE_HZ) * TABLE_SIZE;
}

// ====================== COMANDOS (JSON por línea) ===================
static char rx_line[256];
static uint16_t rx_len = 0;

static void send_json_reply(const JsonDocument& doc) {
  // Serial.write no-bloqueante (mensaje corto)
  char out[256];
  size_t n = serializeJson(doc, out, sizeof(out));
  if (n > 0 && (int)(n + 1) <= Serial.availableForWrite()) {
    Serial.write((const uint8_t*)out, n);
    Serial.write('\n');
  }
}

static void handle_cmd_line(const char* line) {
  JsonDocument doc;
  DeserializationError err = deserializeJson(doc, line);
  JsonDocument rep;

  if (err) {
    rep["ok"] = false;
    rep["err"] = "bad_json";
    send_json_reply(rep);
    return;
  }

  const char* cmd = doc["cmd"] | "";
  if (strcmp(cmd, "state?") == 0) {
    const char* st = (g_state == RUNNING) ? "RUNNING" : (g_state == IDLE ? "IDLE" : "STOPPED");
    rep["ok"]   = true;
    rep["state"]= st;
    rep["drop"] = (uint32_t)drop_count;
    rep["sid"]  = (uint32_t)sample_id;
    send_json_reply(rep);
    return;
  }

  if (!strcmp(cmd,"start")) {
    if (g_state!=RUNNING) { sample_id=0; drop_count=0; g_state=RUNNING; }
    rep["ok"]=true; rep["state"]="RUNNING"; send_json_reply(rep); return;
  }
  if (!strcmp(cmd,"stop")) {
    g_state=STOPPED; rep["ok"]=true; rep["state"]="STOPPED"; send_json_reply(rep); return;
  }


  // ejemplo "set": {"cmd":"set","arg":{"kind":"adc","ch":0,"freq":750.0}}
  if (!strcmp(cmd,"set")) {
    if (g_state==RUNNING) { rep["ok"]=false; rep["err"]="busy_running"; send_json_reply(rep); return; }
    JsonVariant a=doc["arg"];
    const char* kind = a["kind"] | "";
    int ch = a["ch"] | -1;
    float fq = a["freq"] | NAN;
    bool ok=false;
    if (!strcmp(kind,"adc") && ch>=0 && ch<NUM_ADC24 && isfinite(fq) && fq>=0) {
      freq_adc24[ch]=fq; ok=true;
    } else if (!strcmp(kind,"acc") && ch>=0 && ch<NUM_ACC16 && isfinite(fq) && fq>=0) {
      freq_acc16[ch]=fq; ok=true;
    }
    if (ok){ update_phase_steps(); rep["ok"]=true; } else { rep["ok"]=false; rep["err"]="bad_args"; }
    send_json_reply(rep); return;
  }

  // comando desconocido
  rep["ok"] = false;
  rep["err"] = "unknown_cmd";
  send_json_reply(rep);
}

static void poll_serial_commands()
{
  while (Serial.available() > 0) {
    char c = (char)Serial.read();
    if (c == '\n' || c == '\r') {
      if (rx_len > 0) {
        rx_line[rx_len] = '\0';
        handle_cmd_line(rx_line);
        rx_len = 0;
      }
    } else {
      if (rx_len < sizeof(rx_line) - 1) {
        rx_line[rx_len++] = c;
      } else {
        // overflow: resetea
        rx_len = 0;
      }
    }
  }
}

// ============================ SETUP ============================
void setup() {
  // Serial: si es USB CDC, el baud es ignorado (OK); si usas UART, útil tener 1e6.
  Serial.begin(SERIAL_BAUD);
  while (!Serial && millis() < 2000) { /* espera breve */ }

  // LUT de seno
  for (int i = 0; i < TABLE_SIZE; ++i) {
    float ang = (2.0f * PI * i) / (float)TABLE_SIZE;
    sine_table[i] = sinf(ang);
  }

  update_phase_steps();
 Wire1.begin();
 Wire1.setClock(400000);

  if (imu1.init()) { imu1_ok = true; imu1.autoOffsets(); }
  if (imu2.init()) { imu2_ok = true; imu2.autoOffsets(); }

  Serial.println("starting");

  if (imu1_ok) Serial.println("IMU1 detectada en 0x68");
  if (imu2_ok) Serial.println("IMU2 detectada en 0x69");


  // Timer a 5 kHz
  sampler.begin(isr_sample, 1000000.0f / SAMPLE_RATE_HZ);
  sampler.priority(32);   // 0 (altísima) .. 255 (baja). 32 es muy alta sin ser extrema.

}



// ============================= LOOP ============================
void loop() {
  // 1) comandos JSON
  poll_serial_commands();

  // 2) salida no-bloqueante
  int sent = 0;
  while (q_read != q_write && sent < MAX_FRAMES_PER_ITER) {
    int avail = Serial.availableForWrite();
    if (avail < (int)FRAME_BYTES) {
      break; // no hay espacio para un frame completo; salimos
    }
    // escribir exactamente un frame
    Serial.write(tx_queue[q_read], FRAME_BYTES);
    q_read = (q_read + 1) & (TX_QUEUE_LEN - 1);
    sent++;
  }

  // opcional: pequeño yield para dar chance al stack USB
  // (en Teensy 4.x no es crítico, pero ayuda)
  yield();

}

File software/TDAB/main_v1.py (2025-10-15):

#!/usr/bin/env python3
# -*- coding: utf-8 -*-
"""
Integrated GUI: embebe el backend de streaming (SerialReader) en la GUI de Qt Designer (gui.py)

- ADC en graphicsView_9
- Acelerómetros en graphicsView_10
- Botones Start/Stop -> envían JSON {"cmd":"start"} / {"cmd":"stop"} por el mismo puerto
- Checkboxes:
    * checkBox        -> Acelerómetro 1 (X,Y,Z)
    * checkBox_2      -> Acelerómetro 2 (X,Y,Z)
    * checkBox_3..8   -> ADC CH1..CH6

Notas:
- El firmware debe aceptar comandos JSON con salto de línea, p.ej: {"cmd":"start"}\n
- Este script reutiliza el SerialReader probado en teensy_stream_viewer.py
"""
import argparse
import sys
import json
import numpy as np
import serial  # pyserial


import time
from datetime import datetime,timedelta
import struct
import threading
from collections import deque

from PyQt5 import QtWidgets, QtCore
import pyqtgraph as pg

from gui import Ui_MainWindow            # tu UI exportada desde Qt Designer
#from teensy_stream_viewer import SerialReader  # backend de streaming (ya probado)






# -------------------- CONFIGURACIÓN BÁSICA --------------------
DEFAULT_PORT = "/dev/ttyACM0"   # ajusta si es necesario (Windows: COMx, macOS: /dev/cu.usbmodem*)
DEFAULT_BAUD = 1000000          # ignorado por USB CDC, pero requerido por pyserial
DEFAULT_FS   = 50000.0           # Hz (debe coincidir con SAMPLE_RATE_HZ del firmware)
WINDOW_SECS  = 10.0
POINTS_TARGET = int(WINDOW_SECS * DEFAULT_FS)

RUNNING = 1
IDLE = 0
PAUSED = 2


HEADER = b'\xA5\x5A'
FRAME_SIZE = 23
PAYLOAD_SIZE = FRAME_SIZE - 2  # after header

# Si tus nombres de widgets fueran distintos, cambia aquí:
OBJ_GRAPH_ADC = "graphicsView_9"
OBJ_GRAPH_ACC = "graphicsView_10"
OBJ_BTN_START = "pushButton_36"
OBJ_BTN_STOP  = "pushButton_9"
OBJ_CB_ACC1   = "checkBox"
OBJ_CB_ACC2   = "checkBox_2"
OBJ_CBS_ADC   = ["checkBox_3", "checkBox_7", "checkBox_4", "checkBox_6", "checkBox_5", "checkBox_8"]



# DEFAULT PARAMETERS
EEG_BFC = 0.5
ECG_BFC = 0.05
EMG_BFC = 10

EEG_TFC = 100
ECG_TFC = 150
EMG_TFC = 1000

EEG_GAIN = 1000
ECG_GAIN = 160
EMG_GAIN = 80


MIN_PARAM = 0
MAX_PARAM = 100
MODO_MANUAL = 0
MODO_AUTO   = 1


# --- stacking / offsets ---
STACK_ADC = True
STACK_ACC = True

# offsets en unidades de muestra (ajústalos a tu amplitud típica)
OFFSET_ADC = 12000.0   # p.ej. ±10k -> pon 12000
OFFSET_ACC = 12000.0   # idem para acelerómetros

# escala del canal 24b para verse como 16b (si lo sigues usando en CH1)
SCALE_ADC24 = 1.0/256.0

# --------------------------------------------------------------



def crc16_ccitt(data: bytes, init=0xFFFF) -> int:
    """CRC-16/CCITT-FALSE (poly 0x1021, init 0xFFFF)"""
    crc = init
    for b in data:
        crc ^= (b << 8) & 0xFFFF
        for _ in range(8):
            if crc & 0x8000:
                crc = ((crc << 1) ^ 0x1021) & 0xFFFF
            else:
                crc = (crc << 1) & 0xFFFF
    return crc & 0xFFFF


def s24_from_le(b0, b1, b2) -> int:
    """Convert 3 little-endian bytes to signed 24-bit integer."""
    u = b0 | (b1 << 8) | (b2 << 16)
    if u & 0x800000:
        u -= 0x1000000
    return int(u)


class SerialReader(threading.Thread):
    """Background reader that parses frames and pushes them to a ring buffer."""
    def __init__(self, port: str, baud: int, buf_seconds: float, rate: float, verify_crc: bool=True):
        super().__init__(daemon=True)
        self.port = port
        self.baud = baud
        self.verify_crc = verify_crc
        self.stop_flag = threading.Event()
        self.connected = threading.Event()
        self.lost = 0
        self._last_sid = None
        # Preallocate ring buffers (time and 7 channels)
        self.rate = float(rate)
        self.buf_len = int(buf_seconds * self.rate)
        self.t = np.full(self.buf_len, np.nan, dtype=np.float64)
        self.ch = np.full((7, self.buf_len), np.nan, dtype=np.float32)
        self.idx = 0
        self.wraps = 0
        self.lock = threading.Lock()

        self._ser = None
        self._last_sid = None

    def run(self):
        while not self.stop_flag.is_set():
            try:
                self._open()
                self._read_loop()
            except Exception as e:
                # Connection dropped or parse error; attempt reconnect after short delay
                self.connected.clear()
                try:
                    if self._ser:
                        self._ser.close()
                except Exception:
                    pass
                time.sleep(0.5)

    def _open(self):
        self._ser = serial.Serial(self.port, self.baud, timeout=1)
        # For USB CDC, baud is ignored; ok.
        self.connected.set()
        print(f"[OK] Connected to {self.port}")

    def _sync_to_header(self):
        """Find header 0xA5 0x5A in the stream."""
        ser = self._ser
        # Read bytes until we see 0xA5 0x5A
        while not self.stop_flag.is_set():
            b = ser.read(1)
            if not b:
                continue
            if b == b'\xA5':
                b2 = ser.read(1)
                if b2 == b'\x5A':
                    return True
        return False

    def _read_exact(self, n: int) -> bytes:
        ser = self._ser
        buf = bytearray()
        while len(buf) < n and not self.stop_flag.is_set():
            chunk = ser.read(n - len(buf))
            if not chunk:
                break
            buf.extend(chunk)
        return bytes(buf)

    def _read_loop(self):
        ser = self._ser
        while not self.stop_flag.is_set():
            if not self._sync_to_header():
                break
            # Read 21 bytes of payload after header
            payload = self._read_exact(PAYLOAD_SIZE)
            if len(payload) != PAYLOAD_SIZE:
                # Lost sync or timeout; restart sync
                continue

            # Parse fields
            sid = struct.unpack_from('<I', payload, 0)[0]
            # s24 little-endian at offset 4..6
            s24 = s24_from_le(payload[4], payload[5], payload[6])
            acc = struct.unpack_from('<6h', payload, 7)  # int16 * 6
            crc_rx = struct.unpack_from('>H', payload, 19)[0]  # big-endian at last two bytes

            if self._last_sid is not None and sid != (self._last_sid + 1) % (1<<32):
                self.lost += (sid - self._last_sid - 1) % (1<<32)
                self._last_sid = sid

            if self.verify_crc:
                crc_calc = crc16_ccitt(HEADER + payload[:-2])
                if crc_calc != crc_rx:
                    # Bad CRC: drop and resync
                    continue

            # Build timestamps from sample_id to keep perfect time base
            t = sid / self.rate
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

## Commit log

2024-08-29 checking PWR traces on layout
    [EEG_board.csv, EEG_board.kicad_pcb, EEG_board.kicad_sch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]
2024-08-29 starting readme
    [eeg_shield.kicad_pcb, eeg_shield.kicad_sch]
2024-09-26 working on gui adding accel review
    [EEG_board-B_Cu.gbl, EEG_board-B_Mask.gbs, EEG_board-B_Paste.gbp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]
2025-04-29 implementing down sampling
    [EEG_board.csv, EEG_board.kicad_pcb, EEG_board.kicad_sch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]
2025-06-05 adding test adc
2025-08-19 testing core of i2c transmition
    [EEG_board.kicad_sch, datos.csv, untitled.kicad_sch]
2025-09-24 versión 1 del código, considera testear comunicación y graficar en tiempo real. considera firmware y software
    [datos.csv]
